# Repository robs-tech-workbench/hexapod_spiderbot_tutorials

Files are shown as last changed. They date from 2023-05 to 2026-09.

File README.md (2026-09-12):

# Spider Robot Tutorials

## Tutorials on Catch IT

Read the companion articles on [Catch IT — Robert Meisner's website](https://catchit.pl/). These link back to the source code and include build context, tests and limitations.

- [Building My 3D-Printed Hexapod](https://catchit.pl/blog/building-3d-printed-hexapod-spider-robot/)
- [How the Hexapod Control Layers Fit Together](https://catchit.pl/blog/hexapod-servo-calibration-forward-inverse-kinematics/)
- [Building a Hexapod: Tools, Hardware and 3D-Printed Parts](https://catchit.pl/blog/hexapod-build-guide-tools-hardware-and-3d-printed-parts/)
- [Calibrating Hexapod Servos with a Servo Tester](https://catchit.pl/blog/calibrating-hexapod-servos-with-a-servo-tester/)
- [Controlling a Hexapod with a HID Gamepad](https://catchit.pl/blog/controlling-a-hexapod-with-a-hid-gamepad/)
- [Inverse Kinematics for a Hexapod Leg](https://catchit.pl/blog/inverse-kinematics-for-a-hexapod-leg/)
- [Forward Kinematics for a Hexapod Leg](https://catchit.pl/blog/forward-kinematics-for-a-hexapod-leg/)
- [Controlling One Hexapod Leg](https://catchit.pl/blog/controlling-one-hexapod-leg/)

Welcome to the Spider Robot Tutorials repository! This collection of tutorials is designed to help you build, program, and control a hexapod robot. We'll cover everything from the basics of robot mechanics and design to more advanced topics like inverse kinematics and control algorithms. Whether you're a beginner or a seasoned roboticist, there's something here for everyone.
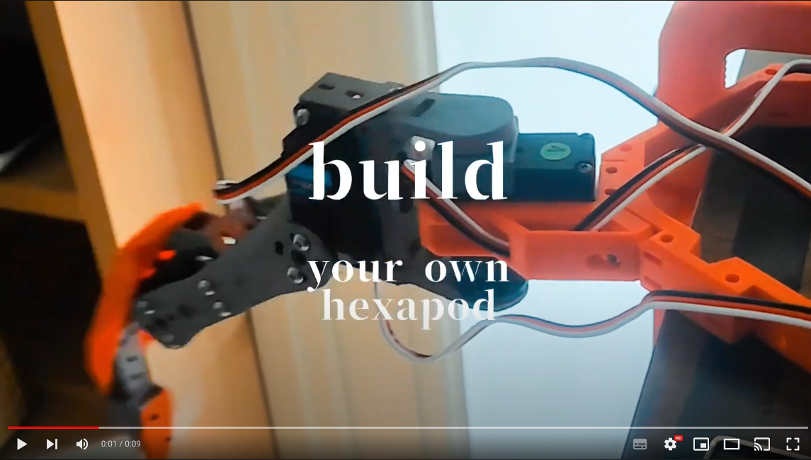
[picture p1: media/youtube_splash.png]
Watch the video (https://youtu.be/toPMHUULjyc)

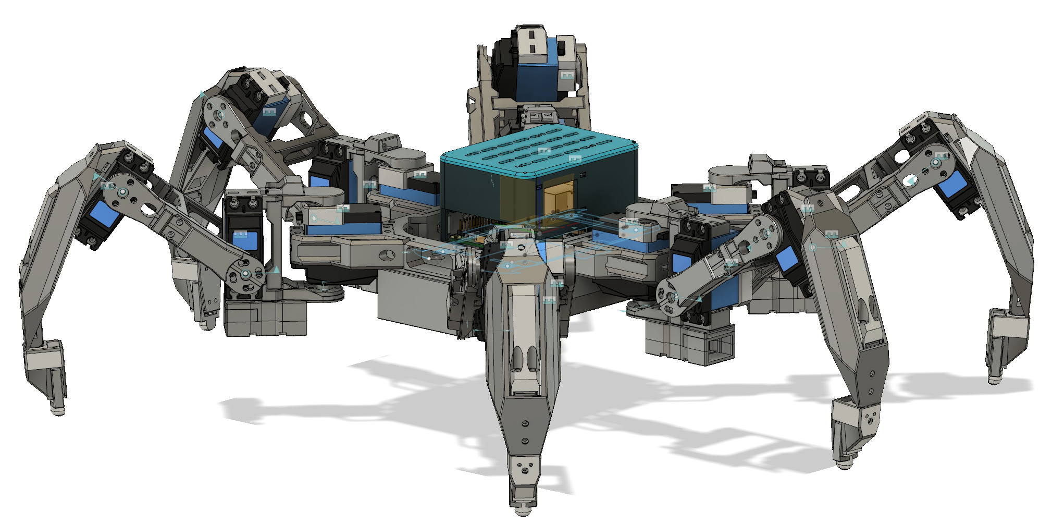
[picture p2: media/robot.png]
Hexapod robot spider

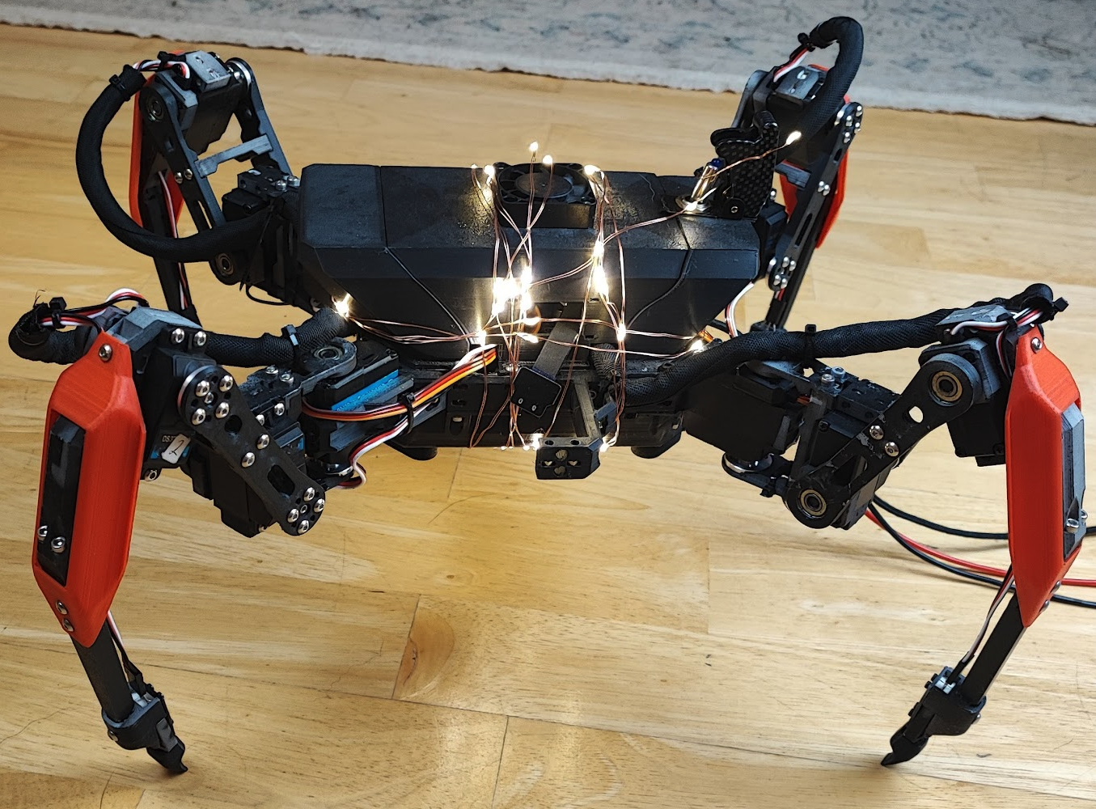
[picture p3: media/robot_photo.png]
SpiderBot photo

## Table of Contents
- Introduction to Hexapod Robotics
- [Tools, Hardware Components, and 3D Printed Parts](tutorial_tools_hardware_3d_parts_spider_robot/README.md)
- [Servo Calibration](tutorial_servo_calibration/README.md)
- [Controlling Your Robot Using USB or Bluetooth HID Devices](tutorial_controlling_robot_using_hid/README.md)
- [Programming the Hexapod: Basics](tutorial_controll_one_leg/README.md)
- [Inverse Kinematics for Spider Robot Legs](tutorial_inverse_kinematics/README.md)
- [Forward Kinematics for Spider Robot Legs](tutorial_forward_kinematics/README.md)
- Gait patterns - TBD
- Control Algorithms and Optimization - TBD
- Adding Sensors and Interactivity - TBD
- Artificial Intelligence - TBD

## Getting Started
To get started with the Spider Robot Tutorials, simply clone this repository or download the tutorials as a ZIP file. Each tutorial folder contains a README.md file, which serves as the main tutorial document. Follow the instructions provided in the README.md files, and you'll be on your way to building and programming your own hexapod robot!

## Contributing
We welcome contributions to the Hexapod Robotics Tutorials repository! If you have a new tutorial idea, an improvement to an existing tutorial, or any other suggestions, please feel free to open an issue or submit a pull request. Notable changes to this repository are tracked in [CHANGELOG.md](CHANGELOG.md).

## License
The content in this repository is licensed. For more information about the license terms and conditions, please refer to the [LICENSE](LICENSE) file in this repository.

Happy building!

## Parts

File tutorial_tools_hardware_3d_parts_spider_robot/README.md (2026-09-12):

Read the companion tutorial on [Catch IT](https://catchit.pl/): [Building a Hexapod: Tools, Hardware and 3D-Printed Parts](https://catchit.pl/blog/hexapod-build-guide-tools-hardware-and-3d-printed-parts/).

# Spider Robot Building Guide: Tools, Hardware Components, and 3D Printed Parts

> **Disclaimer:** This guide is a part of an extensive series focused on constructing a spider robot from scratch. Each installment targets a specific topic to provide you with a comprehensive understanding of the entire process. Whether you are a beginner or an expert in robotics, these resources aim to be both insightful and instructive. Happy building! To access the full series, click [here](../README.md).

## Introduction and Inspiration

The inception of this project can be traced back to a YouTube video from the 'Make Your Own Pet' series. This particular venture piqued my interest as an engaging and educational pastime during the long days of COVID-19 quarantines. To put it in short, the idea is to use a smartphone as the main controller for your hobby project. If you have questions or would like to become part of a community interested in similar projects, I recommend joining their [discord](https://www.makeyourpet.com/) or exploring their [GitHub](https://github.com/makeyourpet/hexapod) and [YouTube](https://www.youtube.com/makeyourpet) channels.
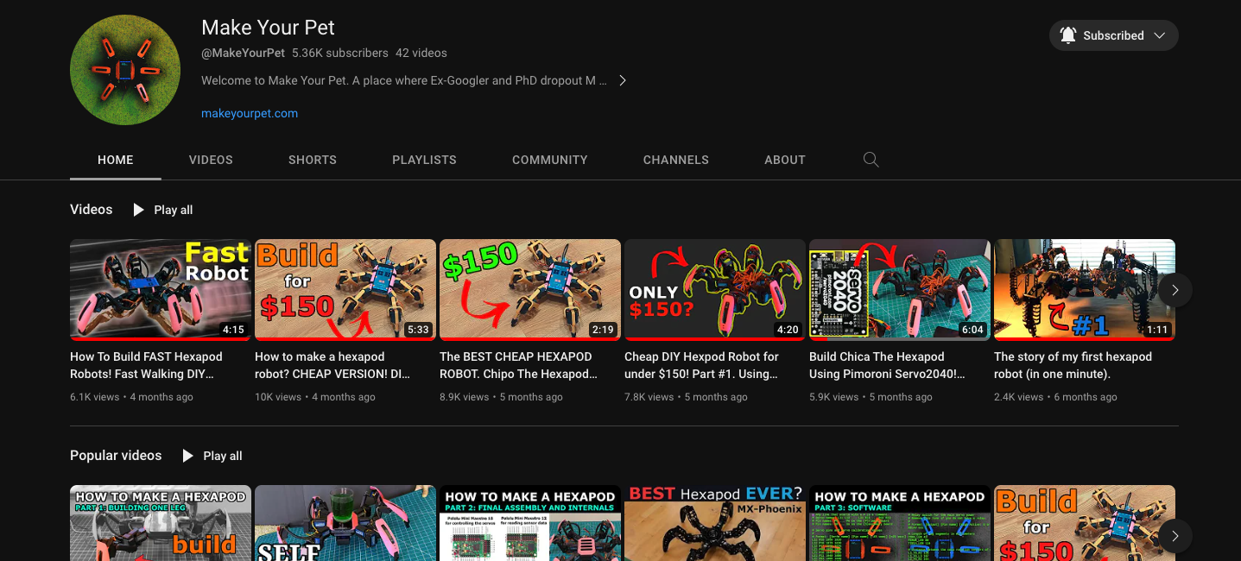
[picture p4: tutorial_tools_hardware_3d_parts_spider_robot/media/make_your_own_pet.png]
Make Your Own Pet

## Affiliation

**I am not affiliated** with any of the companies that manufacture the components used in this project. The links provided are not affiliate links and are included solely for informational purposes. The information is based on my personal experience and is intended for educational use. I strongly recommend conducting your own research and consulting various sources before making any purchasing decisions or implementing these components into your projects.

---
## 3D Printing and Design

**The repository with the most up-to-date 3D parts and other designs can be found here: [https://github.com/robert-s-workshop/hexapod_spiderbot_model](https://github.com/robert-s-workshop/hexapod_spiderbot_model)**

I leveraged Fusion 360 to design custom components for my spider robot, even without extensive CAD experience. I opted for black PLA filament, which offers a good blend of strength, safety, and affordability.

I decided **not to use** the official MakeYourPet 3D parts. Instead, I discovered that one of the Discord server users, named 'amelendez8', was working on his own design [here](https://github.com/almelnz2005/hexapod).
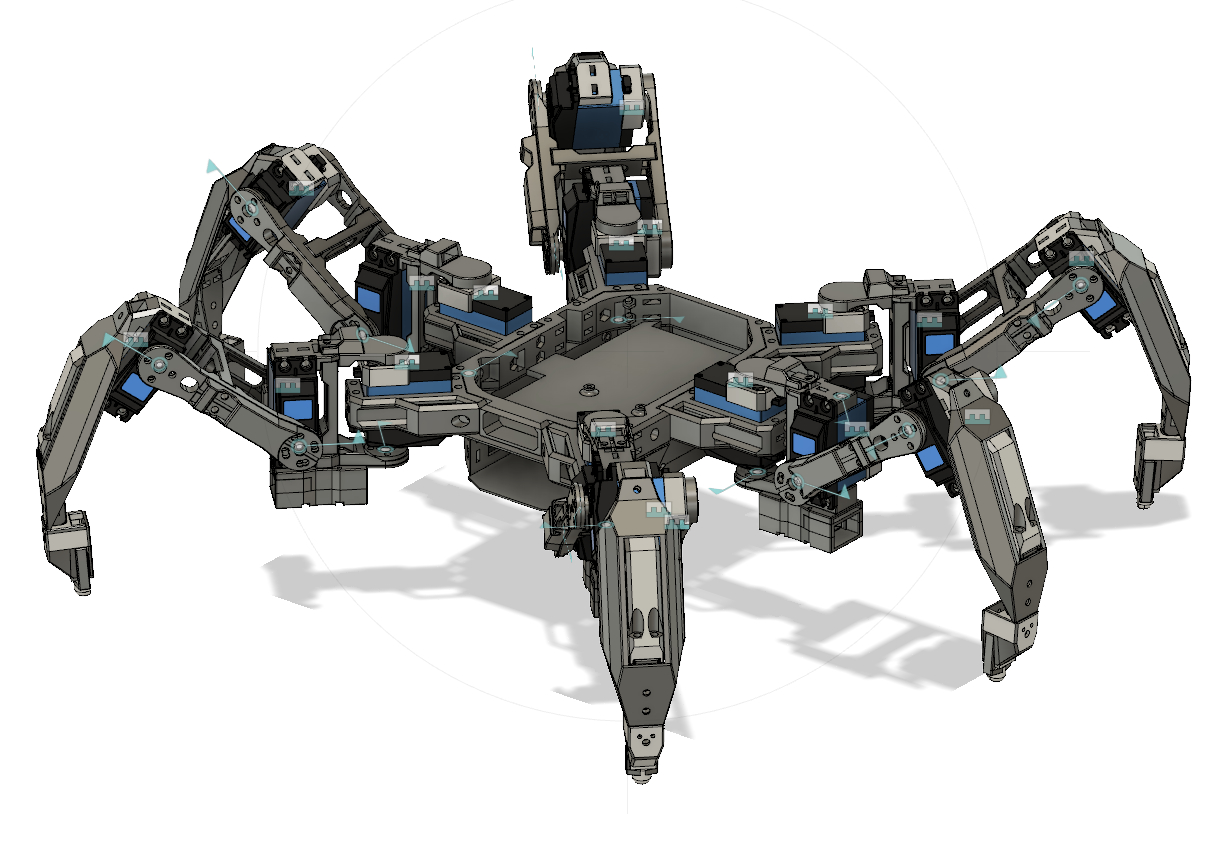
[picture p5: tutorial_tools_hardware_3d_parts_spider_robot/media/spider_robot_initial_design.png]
Original Robot Design


 Since this design was very modular, he shared the source files, the license was permissive, and I liked the techy look and feel, I decided to adjust the design to meet my needs.

The design process was iterative and took considerable time. Initially, I designed a separate enclosure for the Raspberry Pi and servo controller. 
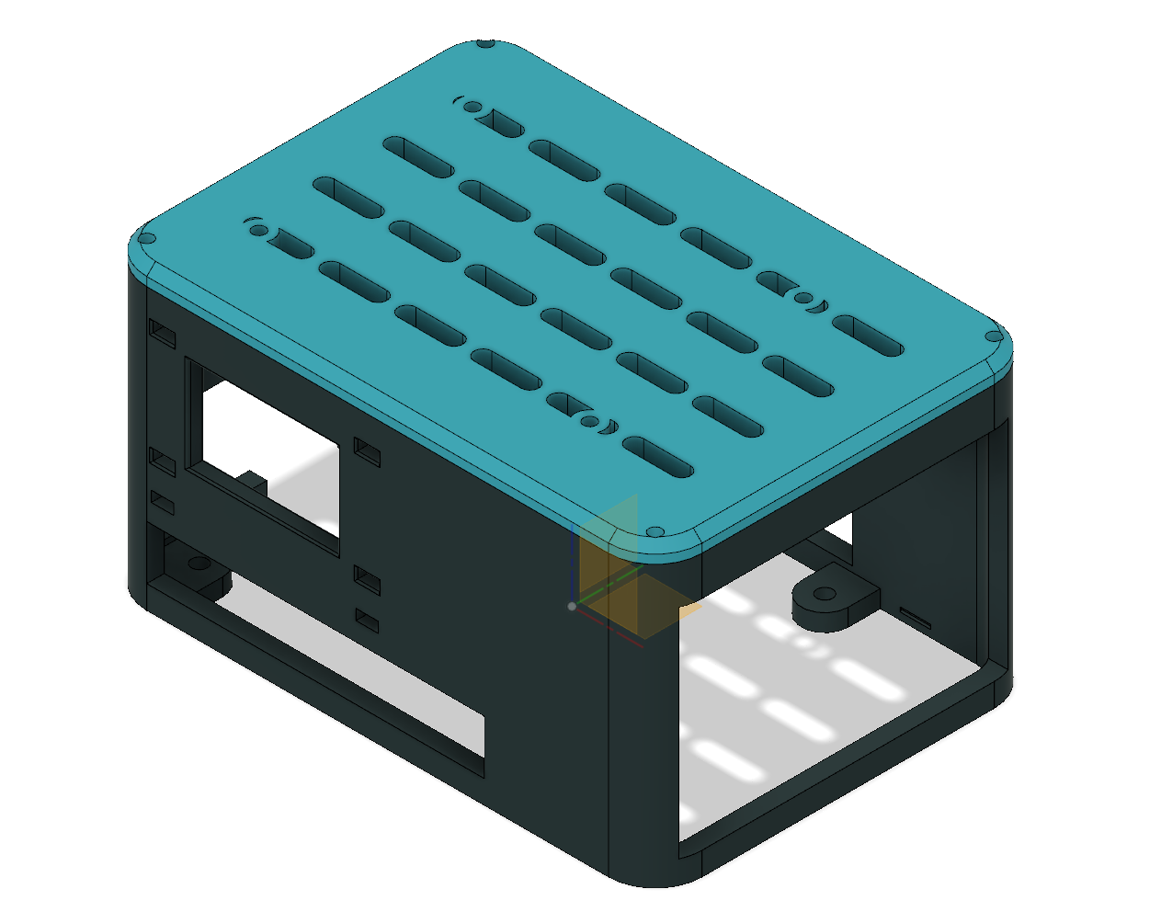
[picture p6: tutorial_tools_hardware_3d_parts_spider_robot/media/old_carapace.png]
New electronics enclosure, robot spider carapace

However, this initial design was visually and functionally disjointed from the overall aesthetic and architecture of the robot.
Realizing the limitations, I opted for a more integrated approach by designing a larger spider robot carapace. 

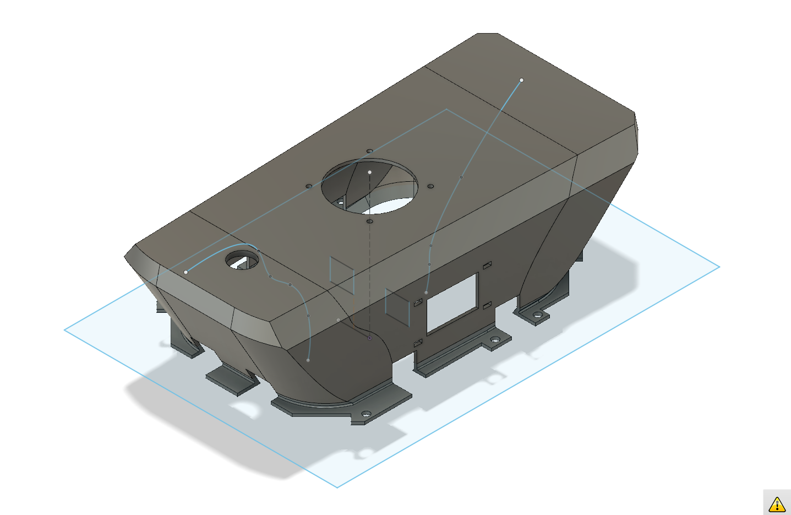
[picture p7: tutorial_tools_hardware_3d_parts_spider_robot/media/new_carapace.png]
New electronics enclosure, robot spider carapace


This new design was superior for several reasons. Firstly, it provided a unified, streamlined look that harmonized with the other modular components. Secondly, the carapace could accommodate and neatly conceal all the electronics, eliminating the clutter of exposed wires and creating a cleaner, more professional appearance. 
Lastly, this unified housing simplified the assembly process, making it easier to access components for future upgrades or maintenance.
First electronics enclosure
I initially made the mistake of placing the Raspberry Pi at the bottom, with the servo controller suspended above it. This configuration made it challenging to open the carapace without detaching all the servo cables. To rectify this, I later repositioned the Raspberry Pi on the roof of the body while keeping the servo controller attached to the floor.

The carapace also underwent several minor modifications to optimize the available internal space.

Next, I decided to replace the bolt-like joint design with one that utilizes bearings. This required reworking every joint in the legs, which basically consisted of two parts.

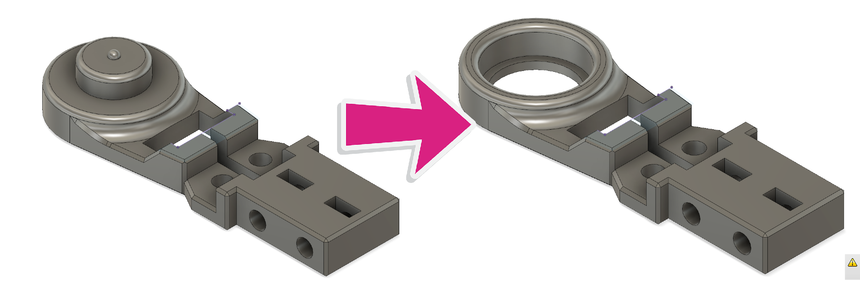
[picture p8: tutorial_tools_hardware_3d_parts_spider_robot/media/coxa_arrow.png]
Bearings, leg joints, coxa

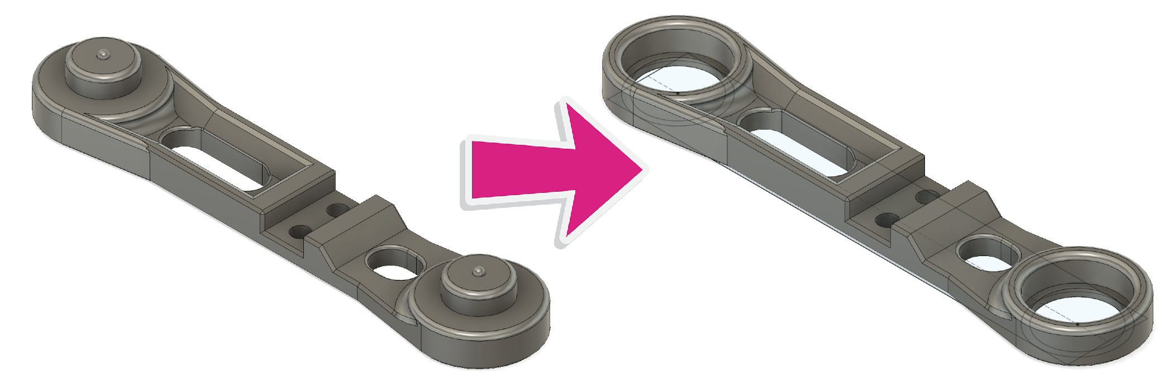
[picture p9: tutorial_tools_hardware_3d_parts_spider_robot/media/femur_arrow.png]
Bearings, leg joints, femur

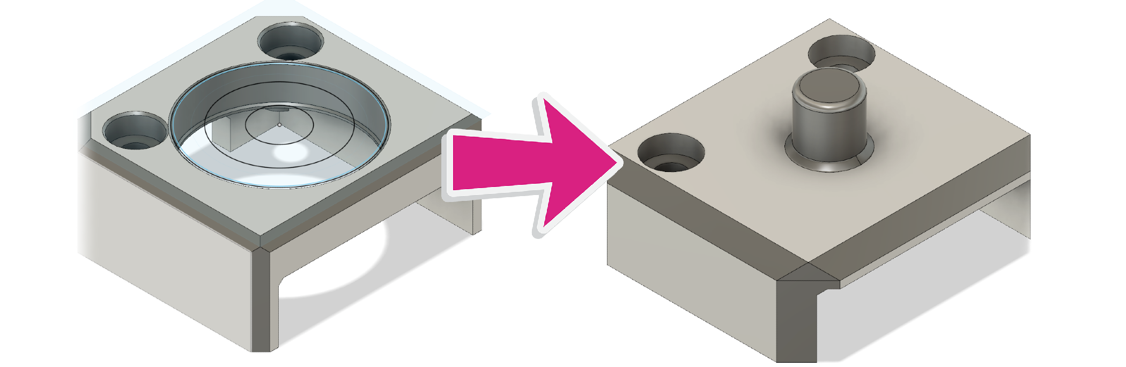
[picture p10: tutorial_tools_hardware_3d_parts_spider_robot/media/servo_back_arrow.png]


Since I started with a quadruped robot, balancing it during walking was a significant challenge. After some tests, I discovered that the robot could benefit from a larger range of movement. To achieve this, I needed to extend the length of the leg's tibia.
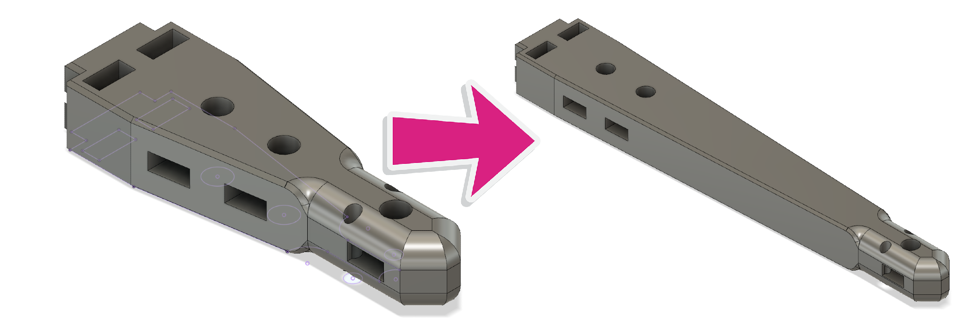
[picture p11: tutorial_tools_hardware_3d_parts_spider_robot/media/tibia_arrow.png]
Spider robot, longer tibia


Finally, I made some holes in the body to accommodate the on/off switch, some LCD screens, and the cooling fan.

Spider robot

**The repository with the most up-to-date design can be found here: [https://github.com/robert-s-workshop/hexapod_spiderbot_model](https://github.com/robert-s-workshop/hexapod_spiderbot_model)**

## Hardware Components

### Servo Motors: Coreless vs. Brushless, Range and Resolution Considerations

When building a spider robot, the type of servo motor you choose is paramount. Coreless high-speed, high-torque servo motors with a rating of 35kg+ are recommended for this project. However, brushless motors with positional feedback provide greater accuracy and longevity, though they come with a hefty price tag. 

Servos

When selecting a servo motor for your project, it's crucial to consider the range of motion you'll need. Servo motors commonly come in ranges like 180° or 270°. A servo with a wider range (e.g., 270°) will offer more flexibility in movement but may have a lower resolution, meaning less precise control over small movements. On the other hand, a 180° servo might offer higher resolution, allowing for more precise positioning but with a limited range. Choose a servo that best fits the specific requirements of your project for optimal performance.
[Servo Motors i have used on Aliexpress](https://pl.aliexpress.com/item/33010787343.html)

### Servo Mounting: Metal 25T Servo Arm Round Type

For robust and reliable servo mounting, I recommend using Metal Servos Mount Aluminum Metal 25T Servo Arm Round Type. These mounts are made of high-quality aluminum, providing excellent durability and stability. The 25T round type design ensures a secure fit and optimal torque transfer, making it an ideal choice for projects that require precise and consistent servo movements.
[Metal Servos Mount Aluminum Metal 25T Servo Arm Round Type on Aliexpress](https://www.aliexpress.com/item/32966238529.html)
Metal 25T Round Servo Arm

### Micro Switches for Leg Sensors

Touch-sensitive micro switches act as leg sensors, providing crucial input for the robot's movement algorithms. 
These can be easily procured from [Amazon](https://www.amazon.co.uk/gp/product/B07YDFH7H3).
Micro Switches for Leg Sensors

### Servo Controller 

The Servo 2040 - 18 Channel Servo Controller is the backbone for servo operations. Its firmware aligns with the 'Make Your Own Pet' project, and I've crafted a Python class for easy communication with the spider's 'brain.'
[Servo 2040 - 18 Channel Servo Controller](https://shop.pimoroni.com/products/servo-2040?variant=39800591679571)
The Servo 2040

#### Why This Controller is a Good Choice
- **Versatile**: Supports up to 18 servos, ideal for complex robotics.
- **Power Monitoring**: Built-in current tracking for optimized power use.
- **Visual Feedback**: Six RGB LEDs for immediate status updates.
- **Sensor Support**: Headers for six analog sensors for added functionalities.
- **RP2040 Core**: Benefits from the flexibility of RP2040's Programmable IOs (PIOs).

### The Spider Brain: Raspberry Pi 4 Model B

A Raspberry Pi 4 Model B or a similar board that supports a Linux-based OS and Python environment is ideal for executing the robot's complex logic. This includes gait algorithms, sensor inputs, and communication with the Gamepad controller.

Raspberry

### Servo Extension Cables 

Investing in both long (30cm) and short (10-15cm) extension cables saves you from having to engage in tedious cable management. 

[Servo Extension Cables on Amazon](https://www.amazon.co.uk/gp/product/B06W9MRNWL).

Servo Extension Cable

### Cable Management: Braided Cable Sleeve PET Self Closing

Effective cable management is crucial for both aesthetics and functionality. I recommend using a Braided Cable Sleeve PET Self Closing for wrapping loose cables. This sleeve is not only easy to use but also provides a clean and organized look to your project. Its self-closing feature ensures that your cables stay securely bundled, reducing the risk of tangling or snagging. 

[Braided Cable Sleeve PET Self Closing on Aliexpress](https://www.aliexpress.com/item/4000279970497.html)

Braided Cable Sleeve

### Bearings

For smooth mechanical performance, bearings are an essential part of the 3D printed components. If you opt for a different 3D model, ensure your bearings are compatible. For my design use model 625zz. There are 3D printed robot designs available that do not need those - just check 'Make Your Own Pet' project.
Bearings

### Power Control: 12V Illuminated LED Toggle Switch Aircraft Missile Flip

To easily control the power supply to the robot, I've used a 12V Illuminated LED Toggle Switch Aircraft Missile Flip. This toggle switch not only serves the functional purpose of turning the robot on and off but also adds a bit of aesthetic appeal with its illuminated LED and aircraft missile flip design.
12V Illuminated LED Toggle Switch Aircraft Missile Flip

### Power Source: 2S Lipo Battery

The Zeee 2S Lipo Battery 6200mAh 7.4V 60C is an excellent fit for this project, easily fitting into the robot's battery compartment. I decided to solder an XT30 plug for compatibility with the rest of my build. 

[The Zeee 2S Lipo Battery 6200mAh 7.4V 60C on amazon UK](https://www.amazon.co.uk/gp/product/B07YD6282M)
Zeee 2S Lipo Battery

### Wires: Selecting the Right Gauge and Insulation

Choosing the correct wires is essential for both the functionality and safety of your project. For signal wires, I highly recommend using 22-24 AWG, as these gauges are generally suitable for low-current signal transmission. For power wires, 14-16 AWG is the go-to choice to ensure they can handle the current without overheating. I strongly advise opting for silicon-covered wires; they offer superior heat resistance and flexibility compared to other types of insulation. Silicon-covered wires are also more manageable when working in tight spaces or routing through complex assemblies.
Silicon Wires

### 5V Step Down Buck Module

To convert the 7.4V from your battery to a stable 5V for the Raspberry Pi, a step-down buck module is essential. Opt for one that can deliver at least 3A of current. 
[2A 5V Step Down Buck Module I have used on Aliexpress (you might need 3A)](https://www.aliexpress.com/item/4000084079149.html)
5V Step Down Buck Module

---

## ⚠️ CRITICAL: Power Safety Warning

**When operating with both battery and USB connected, you MUST take precautions to prevent power backfeed damage.**

### The Risk
Connecting battery power and USB power simultaneously without proper precautions can cause **permanent hardware damage** to your:
- Raspberry Pi (power management IC failure)
- Servo 2040 (power transistor failure, can cause voltage feedback or overcurrent conditions)
- Computer/laptop (via USB backfeed)

### Required Safety Measures

You **MUST** use one of these solutions when connecting battery and USB at the same time:

1. **Use a data-only USB cable** (recommended for development)
   - This is a USB cable with the VBUS (+5V power) pin disconnected while keeping data and ground pins connected
   - Allows programming and communication without power backfeed risk
   - Essential when programming a battery-powered robot through USB

2. **Cut the "Separate USB and Ext. Power" trace** on the Servo 2040 back
   - This physically separates USB power from external battery power on the board
   - See the [Servo 2040 product page](https://shop.pimoroni.com/products/servo-2040) for details
   - Permanent modification - recommended only if you always use external power

### Important Notes
- The Servo 2040 official documentation includes this critical warning that must not be ignored
- **Never connect both battery and standard USB simultaneously** without one of the above precautions
- When in doubt, disconnect the battery before connecting USB for programming
- For production use, choose your power source: battery OR USB, not both

⚠️ **Failure to follow these precautions can result in expensive equipment damage within minutes.**

For more information, refer to the official [Servo 2040 documentation](https://shop.pimoroni.com/products/servo-2040).

---

### USB Cables

Two types of USB cables are needed:
- A short USB-A to USB-C for connecting the Raspberry Pi to the Servo Controller. 
[A short USB-A to USB-C on Aliexpress](https://www.aliexpress.com/item/1005005240135902.html)
- A long USB-A to USB-C for development purposes, allowing seamless interfacing between your laptop and the robot. 
USB Cable

---

## Additional Supplies and Tools

### Gamepad Controller 

A Human Interface Device (HID)-compatible gamepad controller is necessary for direct control of the spider robot's movement. The Radiomaster TX16S is a reliable choice, offering both USB and Bluetooth connectivity (with additional module). You can choose any HID compatible controller.
Radiomaster TX16S

### Screws: Choosing the Right Type and Size

For this project, it's crucial to select the right screws to ensure durability and ease of assembly. I highly recommend using hexagonal bit screws over traditional flat or cross-head screws. They offer superior torque control and are generally easier to work with.  
[You can find sets of these screws available on Amazon UK](https://www.amazon.co.uk/gp/product/B093ZKJHX6).

Hexagonal Bit Screws

**Note**: Be cautious when purchasing screw sets; make sure to buy sets with consistent hex socket sizes. I made the mistake of buying two different sets with varying hex socket sizes, which complicated the assembly process. Two M3 sets (around 500 pieces each) of mixed sizes should have you covered for this project.

### Fasteners/Zip Ties
You will need a lot of zip ties to keep all your cables under control. Zip ties are not only an inexpensive but also an effective solution for managing the maze of wires that power the servos, sensors, and the central processing unit. Opt for a variety pack that includes ties of multiple lengths and widths, as you'll find various applications for each size. High-quality zip ties are recommended for long-lasting durability, especially since the cables will often be in motion, causing wear and tear on the ties themselves.
Fasteners/Zip Ties
## Other Tools
- **Scalpel Knife/Box cutter:** After 3D printing, it's common to have some imperfections or excess material on your parts. A Scalpel Knife is an excellent tool for cleaning up these minor flaws. It allows for precise cuts and can easily remove brims, supports, or any other unwanted material, leaving you with a cleaner, more professional-looking component.
[Scalpel Knife on Aliexpress](https://www.aliexpress.com/item/1005004898484210.html)

- **Soldering Set:** A USB-powered soldering iron is portable and can be used in field adjustments. 
Additionally, a soldering third arm can be incredibly helpful for holding components in place while you work, and a soldering cleaner is essential for maintaining the tip of your soldering iron, thereby ensuring more precise and effective soldering.
Soldering Set
USB-powered soldering iron
- **Mini Cordless Precision Electric Screwdriver:** Given the hundreds of screws you'll be working with, this tool is indispensable.
Mini Cordless Precision Electric Screwdriver
- **Digital Servo/ESC Consistency Tester:** This is crucial for calibrating and testing your servo motors.
Digital Servo/ESC Consistency Tester
- **Multimeter:** It's highly advisable to use a multimeter during the setup and testing phases. A multimeter will allow you to accurately measure voltage, current, and resistance, ensuring that all components, including the Servo Controller or Raspberry, are operating within their specified ranges. This is crucial for both the safety and the successful execution of your project.
Multimeter
---

---

By following this guide, you'll have a comprehensive understanding of the hardware, electronics, and additional supplies needed to build your own spider robot. Feel free to dive into each section for a more in-depth understanding, and happy building!

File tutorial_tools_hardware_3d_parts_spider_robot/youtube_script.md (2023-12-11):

# Spider Robot Building Guide: Tools, Hardware Components, and 3D 

The inception of this project can be traced back to a YouTube video from the 'Make Your Own Pet' series. This particular venture piqued my interest as an engaging and educational pastime during the long days of COVID-19 quarantines. To put it in short, the idea is to use a smartphone as the main controller for your hobby project. If you have questions or would like to become part of a community interested in similar projects, I recommend joining their discord or exploring their GitHub and YouTube channels.

## Disclaimer
**I am not affiliated** with any of the companies that manufacture the components used in this project. The links provided are not affiliate links and are included solely for informational purposes. The information is based on my personal experience and is intended for educational use. I strongly recommend conducting your own research and consulting various sources before making any purchasing decisions or implementing these components into your projects.

---
## 3D Printing and Design

**The repository with the most up-to-date 3D parts and other designs can be found in the description**

I leveraged Fusion 360 to design custom components for my spider robot, even without extensive CAD experience. I opted for black PLA filament, which offers a good blend of strength, safety, and affordability.

I decided **not to use** the official MakeYourPet 3D parts. Instead, I discovered that one of the Discord server users, named 'amelendez8', was working on his own design.

 Since this design -was very modular, -he shared the source files, the license was permissive, -and I liked the techy look and feel, 
 I decided to adjust the design to meet my needs.

The design process was iterative and took considerable time. Initially, I designed a separate enclosure for the Raspberry Pi and servo controller. 
However, this initial design was visually and functionally disjointed from the overall aesthetic and architecture of the robot.
Realizing the limitations, I opted for a more integrated approach by designing a larger spider robot carapace. 

This new design was superior for several reasons. Firstly, it provided a unified, streamlined look that harmonized with the other modular components. Secondly, the carapace could accommodate and neatly conceal all the electronics, eliminating the clutter of exposed wires and creating a cleaner, more professional appearance. 
Lastly, this unified housing simplified the assembly process, making it easier to access components for future upgrades or maintenance.

I initially made the mistake of placing the Raspberry Pi at the bottom, with the servo controller suspended above it. This configuration made it challenging to open the carapace without detaching all the servo cables. To rectify this, I later repositioned the Raspberry Pi on the roof of the body while keeping the servo controller attached to the floor.

The carapace also underwent several minor modifications to optimize the available internal space.

Next, I decided to replace the bolt-like joint design with one that utilizes bearings. This required reworking every joint in the legs, which basically consisted of two parts.

Since I started with a quadruped robot, balancing it during walking was a significant challenge. After some tests, I discovered that the robot could benefit from a larger range of movement. To achieve this, I needed to extend the length of the leg's tibia.

Finally, I made some holes in the body to accommodate the on/off switch, some LCD screens, and the cooling fan.

**The repository with the most up-to-date design can be found in the description**

When building a spider robot, the type of servo motor you choose is paramount. Coreless high-speed, high-torque servo motors with a rating of 35kg+ are recommended for this project. However, brushless motors with positional feedback provide greater accuracy and longevity, though they come with a hefty price tag. 

When selecting a servo motor for your project, it's crucial to consider the range of motion you'll need. Servo motors commonly come in ranges like 180° or 270°. A servo with a wider range will offer more flexibility in movement but may have a lower resolution, meaning less precise control over small movements. On the other hand, a 180° servo might offer higher resolution, allowing for more precise positioning but with a limited range. Choose a servo that best fits the specific requirements of your project for optimal performance.

### Servo Mounting: Metal 25T Servo Arm Round Type

For robust and reliable servo mounting, I recommend using Metal and Round servo arm. These mounts are made of high-quality aluminum, providing excellent durability and stability. The 25T round design ensures a secure fit and optimal torque transfer, making it an ideal choice for projects that require precise and consistent servo movements.

### Micro Switches for Leg Sensors

Touch-sensitive micro switches act as leg sensors, providing crucial input for the robot's movement algorithms. 

### Servo Controller 

The Servo 2040 - 18 Channel Servo Controller is the backbone for servo operations. Its firmware aligns with the 'Make Your Own Pet' project, and I've crafted a Python class for easy communication with the spider's 'brain.'

Why This Controller is a Good Choice?
Well, It supports up to 18 servos, ideal for complex robotics.
It has a Built-in current tracking for optimized power use.
It provides Visual Feedback with Six RGB LEDs for immediate status updates.
It supports up to six analog sensors for added functionalities.
It Benefits from the flexibility of RP2040's Programmable IOs .

### The Spider Brain: Raspberry Pi 4 Model B

A Raspberry Pi 4 Model B or a similar board that supports a Linux-based OS and Python environment is ideal for executing the robot's complex logic. This includes gait algorithms, sensor inputs, and communication with the Gamepad controller.

### Servo Extension Cables 

Investing in both long (30cm) and short (10-15cm) extension cables saves you from having to engage in tedious cable management. 

### Cable Management: Braided Cable Sleeve PET Self Closing

Effective cable management is crucial for both aesthetics and functionality. I recommend using a Braided Cable Sleeve PET Self Closing for wrapping loose cables. This sleeve is not only easy to use but also provides a clean and organized look to your project. Its self-closing feature ensures that your cables stay securely bundled, reducing the risk of tangling or snagging. 

### Bearings

For smooth mechanical performance, bearings are an essential part of the 3D printed components. If you opt for a different 3D model, ensure your bearings are compatible. For my design use model 625zz. There are 3D printed robot designs available that does not need those - just check 'Make Your Own Pet' project.

### Power Control: 12V Illuminated LED Toggle Switch Aircraft Missile Flip

To easily control the power supply to the robot, I've used a 12V Illuminated LED Toggle Switch Aircraft Missile Flip. This toggle switch not only serves the functional purpose of turning the robot on and off but also adds a bit of aesthetic appeal with its illuminated LED and aircraft missile flip design.

### Power Source: 2S Lipo Battery

The Zeee 2S Lipo Battery 6200mAh 7.4V 60C is an excellent fit for this project, easily fitting into the robot's battery compartment. I decided to solder an XT30 plug for compatibility with the rest of my build. 

### Wires: Selecting the Right Gauge and Insulation

Choosing the correct wires is essential for both the functionality and safety of your project. For signal wires, I highly recommend using 22-24 AWG, as these gauges are generally suitable for low-current signal transmission. For power wires, 14-16 AWG is the go-to choice to ensure they can handle the current without overheating. I strongly advise opting for silicon-covered wires; they offer superior heat resistance and flexibility compared to other types of insulation. Silicon-covered wires are also more manageable when working in tight spaces or routing through complex assemblies.

### 5V Step Down Buck Module

To convert the 7.4V from your battery to a stable 5V for the Raspberry Pi, a step-down buck module is essential. Opt for one that can deliver at least 3A of current. 

### USB Cables

Two types of USB cables are needed:
- A short USB-A to USB-C for connecting the Raspberry Pi to the Servo Controller. 

- A long USB-A to USB-C for development purposes, allowing seamless interfacing between your laptop and the robot. 

---

## Additional Supplies and Tools

### Gamepad Controller 

A Human Interface Device (HID)-compatible gamepad controller is necessary for direct control of the spider robot's movement. The Radiomaster XT16S is a reliable choice, offering both USB and Bluetooth connectivity (with additional module). You can choose any HID compatible controller.

### Screws: Choosing the Right Type and Size

For this project, it's crucial to select the right screws to ensure durability and ease of assembly. I highly recommend using hexagonal bit screws over traditional flat or cross-head screws. They offer superior torque control and are generally easier to work with.  

**Note**: Be cautious when purchasing screw sets; make sure to buy sets with consistent hex socket sizes. I made the mistake of buying two different sets with varying hex socket sizes, which complicated the assembly process. Two M3 sets (around 500 pieces each) of mixed sizes should have you covered for this project.

### Fasteners/Zip Ties
You will need a lot of zip ties to keep all your cables under control. Zip ties are not only an inexpensive but also an effective solution for managing the maze of wires that power the servos, sensors, and the central processing unit. Opt for a variety pack that includes ties of multiple lengths and widths, as you'll find various applications for each size. High-quality zip ties are recommended for long-lasting durability, especially since the cables will often be in motion, causing wear and tear on the ties themselves.

## Other Tools
- **Scalpel Knife/Box cutter:** After 3D printing, it's common to have some imperfections or excess material on your parts. A Scalpel Knife is an excellent tool for cleaning up these minor flaws. It allows for precise cuts and can easily remove brims, supports, or any other unwanted material, leaving you with a cleaner, more professional-looking component.

- **Soldering Set:** A USB-powered soldering iron is portable and can be used in field adjustments. 
Additionally, a soldering third arm can be incredibly helpful for holding components in place while you work, and a soldering cleaner is essential for maintaining the tip of your soldering iron, thereby ensuring more precise and effective soldering.

- **Mini Cordless Precision Electric Screwdriver:** Given the hundreds of screws you'll be working with, this tool is indispensable.

- **Digital Servo/ESC Consistency Tester:** This is crucial for calibrating and testing your servo motors.

- **Multimeter:** It's highly advisable to use a multimeter during the setup and testing phases. A multimeter will allow you to accurately measure voltage, current, and resistance, ensuring that all components, including the Servo Controller or Raspberry, are operating within their specified ranges. This is crucial for both the safety and the successful execution of your project.

---

---

By following this guide, you'll have a comprehensive understanding of the hardware, electronics, and additional supplies needed to build your own spider robot. Feel free to dive into each section for a more in-depth understanding, and happy building!

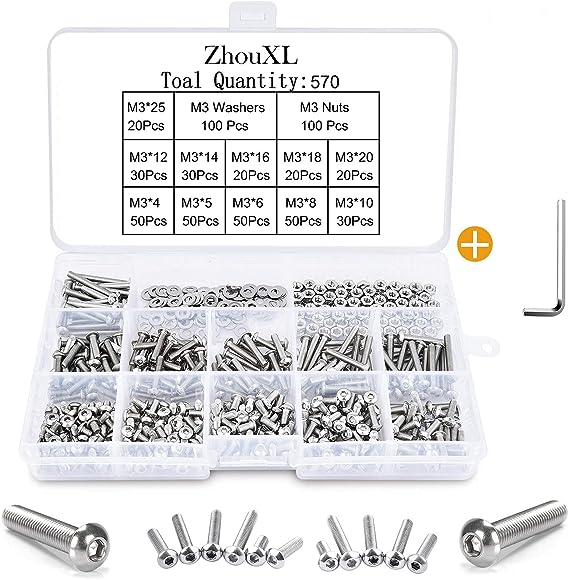
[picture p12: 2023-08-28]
tutorial_tools_hardware_3d_parts_spider_robot/media/81YxCIYD7zL._AC_SX569_.jpg

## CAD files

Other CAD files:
tutorial_inverse_kinematics/Hexapod_Leg_Fusion360.f3d

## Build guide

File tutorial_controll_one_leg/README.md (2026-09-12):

Read the companion tutorial on [Catch IT](https://catchit.pl/): [Controlling One Hexapod Leg](https://catchit.pl/blog/controlling-one-hexapod-leg/).

> **Disclaimer:** This tutorial is part of a comprehensive series that I've created to guide you through the process of building a spider robot. Each tutorial in the series is designed to cover a specific aspect of the project, providing detailed instructions and insights to help you understand and replicate the steps.
> 
> You can find the entire series [here](../README.md). I encourage you to explore all the tutorials in the series to gain a complete understanding of the project. Whether you're a beginner or an expert, I hope you find these resources helpful and informative. Happy building!

# Controlling One Hexapod Leg

This tutorial covers the basics of programming the hexapod: the `SpiderLeg` class with forward and inverse kinematics, simulation and visualization of a single leg, and mapping joint angles to servo pulse widths on the real hardware.

## Resources

- [`spider_leg.py`](spider_leg.py) — the `SpiderLeg` class implementing forward and inverse kinematics for a three-joint leg (coxa, femur, tibia).
- [`one_leg_controll.ipynb`](one_leg_controll.ipynb) — Jupyter notebook that simulates the leg, moves the tip through a set of positions, and projects paths onto the plane defined by those positions.
- [`image_processing.ipynb`](image_processing.ipynb) — image processing helper notebook (OpenCV): it turns a drawing ([`rip.jpg`](rip.jpg)) into paths that can be projected onto the leg's working plane.
- [`hardware_controller.py`](hardware_controller.py) — the `Servo`, `HardwareController`, and `ChicaController` classes for converting joint angles to servo pulse widths and communicating with the servo controller over serial.

The servo configuration file used by `HardwareController` is described in the [Servo Calibration](../tutorial_servo_calibration/README.md) tutorial.

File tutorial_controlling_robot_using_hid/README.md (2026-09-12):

Read the companion tutorial on [Catch IT](https://catchit.pl/): [Controlling a Hexapod with a HID Gamepad](https://catchit.pl/blog/controlling-a-hexapod-with-a-hid-gamepad/).

> **Disclaimer:** This tutorial is part of a comprehensive series that I've created to guide you through the process of building a spider robot. Each tutorial in the series is designed to cover a specific aspect of the project, providing detailed instructions and insights to help you understand and replicate the steps.
> 
> You can find the entire series [here](../README.md). I encourage you to explore all the tutorials in the series to gain a complete understanding of the project. Whether you're a beginner or an expert, I hope you find these resources helpful and informative. Happy building!

## Tutorial: Controlling a Robot with a HID Game Controller

In this tutorial, we will learn how to use the `GamepadController` class I wrote to interact with a game controller as a Human Interface Device (HID) and finally control your robot. 
The tutorial covers the following steps:

1. Listing all HID devices
2. Connecting to a HID device
3. Understanding the raw output from the controller and the two-value transmission per channel
4. Identifying controller channels and configuring them
5. Writing a method to control a robot using the game controller

## Resources

This repository includes a [Jupyter Notebook](controlling_robot_using_hid.ipynb) that contains the code and visualizations. 

### Step 1: Listing all HID devices

Before we can use a HID device, we need to know its vendor ID, product ID, or name. The `list_hid_devices()` method in the `GamepadController` class can be used to list all connected HID devices along with their vendor IDs, product IDs, and names:

```python
GamepadController.list_hid_devices()

```

This static method will list all the HID devices connected to your computer, showing their vendor and product IDs as well as their product strings (names).

### Step 2: Connecting to a HID device
Once we know the vendor ID, product ID, or name of our game controller, we can use the connect() method to establish a connection:

```python
gamepad = hid.device()
controller = GamepadController(gamepad)
controller.connect(vendor_id=<vendor_id>, product_id=<product_id>)  # Replace with actual IDs
# OR
controller.connect(name=<device_name>)  # Replace with actual name
```

This will connect to the HID device with the given vendor ID and product ID, or name.

### Step 3: Understanding the raw output from the controller and the two-value transmission per channel
To better understand the raw output data from the HID device, you can use the print_raw_data() method:
```python
GamepadController.print_raw_data(gamepad)
```
This method will print the raw data received from the controller. Understanding this data is crucial for interpreting the controller's inputs.

Typically, a single channel of a HID device transmits information using two values: a base value and a multiplier. These two values are combined to create a larger data range. In the GamepadController class, this is handled in the process_input() method:

```python
def process_input(self, input_data):
    for channel, index in self.channels.items():
        first_byte = input_data[index]
        multiplier = input_data[index + 1]
        value = 255 * multiplier + first_byte
        self.channel_states[channel] = value
```
The first_byte is the base value, and multiplier is used to increase the range of the possible values. The final value for the channel is calculated by multiplying the multiplier by 255 and adding the base value.

To identify which channels correspond to which controller inputs, you can experiment by moving different parts of your controller and observing the changes in the raw data output. This will help you identify which indexes correspond to which controller inputs.

### Step 4: Identifying controller channels and configuring them
The GamepadController class allows you to define channels such as throttle, roll, yaw, and pitch. After identifying the channels by observing the changes in raw data output during different controller inputs, you can define the channels as follows:

```python
controller = GamepadController(gamepad, channels={'throttle': 0, 'roll': 1, 'yaw': 2, 'pitch': 3})
```

Then you can use the read_controller() method to read the current state of the game controller:

```python
controller_state = controller.read_controller()
print(controller_state)
```

The read_controller() method returns a dictionary containing the current state of all the defined channels.

### Step 5: Writing a method to control a robot using the game controller
With the ability to read the state of the game controller, you can now use this information to control a robot. The following is a simple pseudocode example of how to do this:

```python
while True:
    # Read the controller state (returns None when no new report is available)
    controller_state = controller.read_controller()

    if controller_state:
        # Get the state of the throttle and yaw channels
        throttle = controller_state.get('throttle')
        yaw = controller_state.get('yaw')

        # Use the throttle and yaw values to control the robot
        robot.move_forward(throttle)
        robot.turn(yaw)

    # Wait a short period of time before the next iteration
    time.sleep(0.1)
```
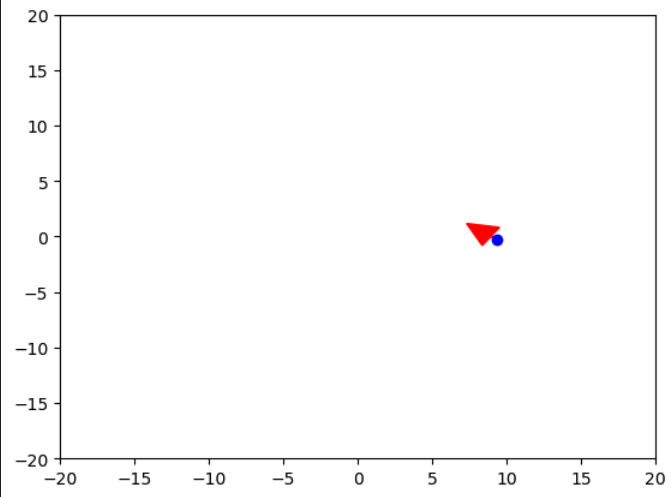
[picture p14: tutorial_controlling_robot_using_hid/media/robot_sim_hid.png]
Robot simulation using HID device


### Oh... Wait! What is HID?

HID stands for Human Interface Device. It's a type of computer device that interacts directly with, and most often takes input from, humans and may deliver output to humans. The term "HID" most commonly applies to the USB-HID specification. The USB-HID specification defines a device class (a type of computer hardware) that includes devices like keyboards, mice, game controllers, and even some more unusual devices like barcode readers.

HID devices are designed to be plug-and-play, which means that when you plug one of these devices into your computer, the operating system should automatically recognize it and load the appropriate drivers.

To identify a HID device, you can look for the following indicators:

1. Vendor ID and Product ID: Every USB device has a vendor ID and a product ID that uniquely identifies it. The vendor ID is a unique number assigned to the manufacturer by the USB standards group, and the product ID is chosen by the manufacturer and is unique to each product they make. You can see these IDs by inspecting the device's properties in your operating system's device manager, or by using software tools that list USB devices (like lsusb on Linux).
2. Device Class: The device class tells the operating system what type of device it is and how it should be handled. HID devices have a device class of 03.
3. Usage Page and Usage ID: The usage page and usage ID are part of the HID specification, and they tell the operating system what kind of input or output the device provides. For example, a mouse might have a usage page of 01 (Generic Desktop Controls) and a usage ID of 02 (Mouse).
4. In Python, you can use the hid library to interact with HID devices. You can list all HID devices connected to your computer using the hid.enumerate() function, which returns a list of dictionaries. Each dictionary contains information about one HID device, including its vendor ID, product ID, usage page, and usage ID.

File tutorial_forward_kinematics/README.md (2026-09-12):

Read the companion tutorial on [Catch IT](https://catchit.pl/): [Forward Kinematics for a Hexapod Leg](https://catchit.pl/blog/forward-kinematics-for-a-hexapod-leg/).

> **Disclaimer:** This tutorial is part of a comprehensive series that I've created to guide you through the process of building a spider robot. Each tutorial in the series is designed to cover a specific aspect of the project, providing detailed instructions and insights to help you understand and replicate the steps.
> 
> You can find the entire series [here](../README.md). I encourage you to explore all the tutorials in the series to gain a complete understanding of the project. Whether you're a beginner or an expert, I hope you find these resources helpful and informative. Happy building!

## Resources

This repository includes a [Jupyter Notebook](forward_kinematics.ipynb) that contains the code and visualizations. 

# Understanding the Forward Kinematics Method in a Spider Robot

Welcome, coding enthusiasts and aspiring roboticists! My goal is to document my journey of building a spider robot in the form of short but detailed tutorials. These tutorials will be easy for everyone to follow, packed with code examples and thorough explanations. Whether you're a seasoned coder or a beginner just starting out, I believe these guides will be a valuable resource in your learning journey. 

Today, in this installment of our exciting series on building a spider robot, we're going to delve into a vital aspect of robot motion planning - the forward kinematics method. Specifically, we'll be exploring the `forward_kinematics_naive` method in our `SpiderLeg` class.

# Forward Kinematics in Robotics

Forward kinematics is a term in robotics that refers to the calculation of the end effector's position (for instance, a robot arm's or a leg's tip position) given the joint angles. It's essentially about predicting the pose of a robot given its joint parameters.

For a spider-like robot, which could be a quadruped (4-legged) or hexapod (6-legged) robot, forward kinematics would involve determining the position of each of its feet given the angles of its joints. Each leg of the robot is typically a kinematic chain, with joints that allow movements in specific directions.

In practical terms, forward kinematics allows the robot to plan its movements. If the robot's brain decides to move a specific leg to a certain position, it can use inverse kinematics to calculate the necessary joint angles, then move the joints to those angles, and use forward kinematics to check that the leg ended up in the right place.

## Brief Introduction to Trigonometry

Before we dive into the code, let's briefly touch upon some basic trigonometry concepts that are used in this method:

- **Sine (sin)**: In a right-angled triangle, the sine of an angle is the length of the side opposite to that angle divided by the length of the hypotenuse (the longest side, opposite the right angle). This is expressed as: \(\sin(\theta) = \frac{{\text{{opposite}}}}{{\text{{hypotenuse}}}}\).

- **Cosine (cos)**: Similarly, the cosine of an angle in a right-angled triangle is the length of the side adjacent to the angle divided by the length of the hypotenuse. This is expressed as: \(\cos(\theta) = \frac{{\text{{adjacent}}}}{{\text{{hypotenuse}}}}\).

- **Tangent (tan)**: The tangent of an angle is defined as the ratio of the sine to the cosine of that angle, or equivalently, the ratio of the side opposite the angle to the side adjacent to the angle in a right-angled triangle. This is expressed as: \(\tan(\theta) = \frac{{\sin(\theta)}}{{\cos(\theta)}}\).

- **Pythagorean theorem**: In any right-angled triangle, the square of the length of the hypotenuse (the side opposite the right angle) is equal to the sum of the squares of the lengths of the other two sides. This can be written as \(a^2 + b^2 = c^2\), where \(c\) is the length of the hypotenuse, and \(a\) and \(b\) are the lengths of the other two sides.

These concepts allow us to calculate the lengths of sides in a right triangle when an angle is known, or to find an angle when the lengths of the sides are known. They form the basis for many geometric calculations and transformations, including those used in our forward kinematics.

Let's get started!

# The `forward_kinematics_naive` Method: A Deep Dive

In this tutorial, we'll dissect the `forward_kinematics_naive` method from the `SpiderLeg` class in our spider robot project. This method is pivotal for calculating the positions of the leg's joints based on the joint angles. Here's a detailed breakdown of each step, complete with trigonometry explanations and inline code snippets.
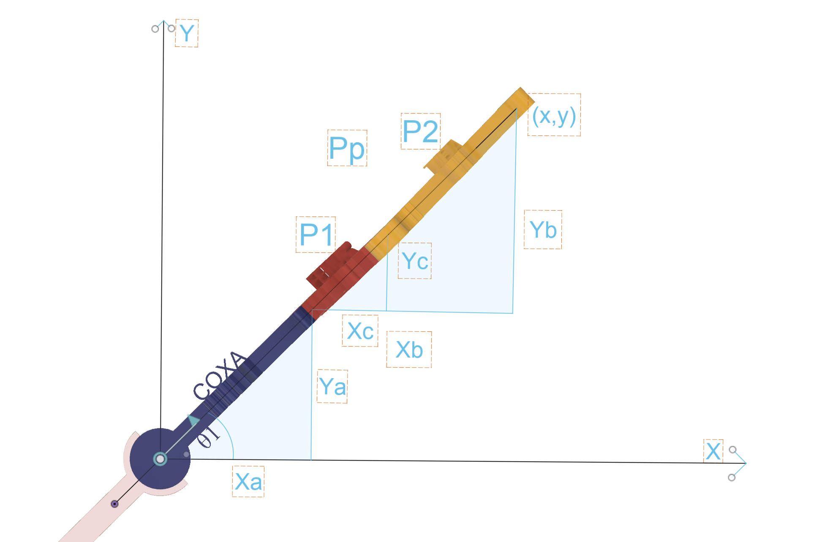
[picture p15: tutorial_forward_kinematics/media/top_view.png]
Spider robot leg top view

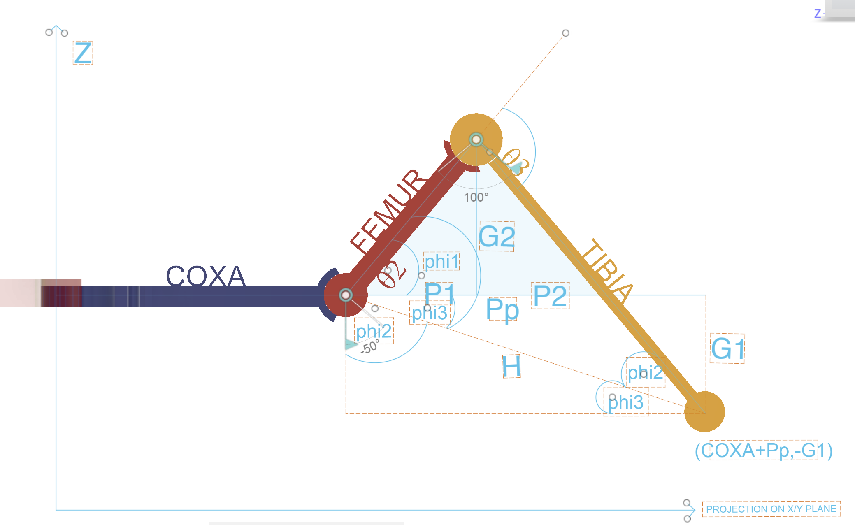
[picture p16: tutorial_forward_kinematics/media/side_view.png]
Spider robot leg side view

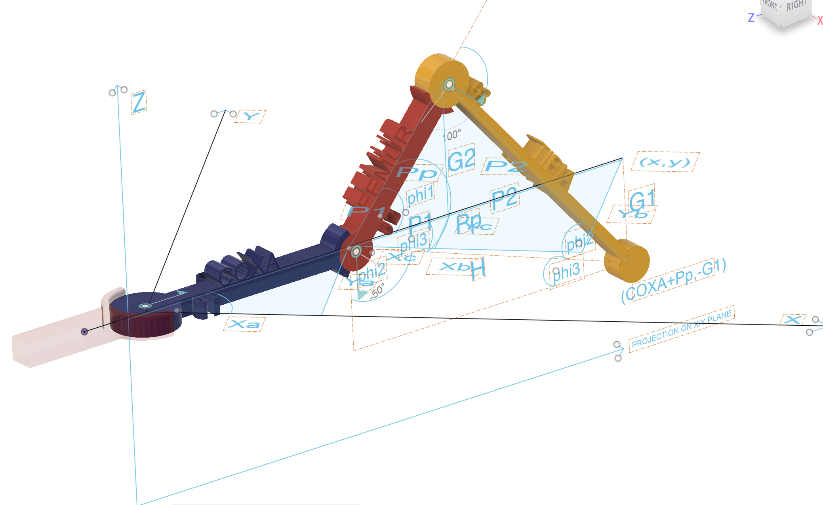
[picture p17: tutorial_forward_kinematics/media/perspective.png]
Spider robot leg perspective


1. **Angle Conversion**:
   The method begins by converting the joint angles from degrees to radians. This conversion is essential as trigonometric functions in Python's math library require angles in radians.

   ```python
   theta1, theta2, theta3 = map(math.radians, self.get_angles())
   ```

2. **Coxa-Femur Joint Calculation**:
   - `Xa` and `Ya` determine the x and y coordinates of the coxa-femur joint (the hip joint). They are calculated using the cosine and sine of `theta1`, respectively, multiplied by the length of the coxa (`self.COXA`). Cosine gives the horizontal component, and sine provides the vertical component.

     ```python
     Xa = self.COXA * math.cos(theta1)
     Ya = self.COXA * math.sin(theta1)
     ```

3. **Femur Segment Calculations**:
   - The vertical component `G2` of the femur length is calculated by the femur length (`self.FEMUR`) multiplied by the sine of `theta2`. This gives the vertical displacement.
   - The horizontal component `P1` is found by multiplying the femur length by the cosine of `theta2`. This gives the horizontal displacement.

     ```python
     G2 = math.sin(theta2) * self.FEMUR
     P1 = math.cos(theta2) * self.FEMUR
     ```

4. **Femur-Tibia Joint Calculation**:
   - `Xc` and `Yc` are the x and y coordinates of the femur-tibia joint (knee joint), computed by multiplying `P1` with the cosine and sine of `theta1`.

     ```python
     Xc = math.cos(theta1) * P1
     Yc = math.sin(theta1) * P1
     ```

5. **Tibia-Tip Joint Calculation**:
   - This step involves calculating the position of the tibia-tip joint (foot of the leg) using a series of trigonometric calculations.
   - `H` is the straight-line distance from the femur-tibia joint to the tibia-tip joint, calculated using the Law of Cosines.

     ```python
     H = math.sqrt(self.TIBIA**2 + self.FEMUR**2 - 2*self.TIBIA*self.FEMUR*math.cos(math.radians(180) - theta3))
     ```

   - `phi1` is calculated using the Law of Cosines again, to find the angle at the femur-tibia joint.

     ```python
     phi1 = math.acos((self.FEMUR**2 + H**2 - self.TIBIA**2) / (2*self.FEMUR*H))
     ```

   - `phi2` is the angle at the tibia-tip joint. It's calculated by subtracting `phi1` and the external angle \( 180^\circ - \theta3 \) from 180 degrees.
   - `phi3` is an auxiliary angle, used to find the horizontal and vertical projections. It's calculated by subtracting `theta2` from `phi1`.

     ```python
     phi2 = math.radians(180) - (math.radians(180) - theta3) - phi1
     phi3 = phi1 - theta2
     ```

   - `Pp` is the horizontal projection of the tibia-tip joint on the plane of the femur. It is calculated using the cosine of `phi3` multiplied by `H`.

     ```python
     Pp = math.cos(phi3) * H
     ```

   - `P2` is the horizontal distance between the femur-tibia joint and the tibia-tip joint. It is calculated as the difference between `Pp` and `P1`.

     ```python
     P2 = Pp - P1
     ```

   - `Yb` and `Xb` are the x and y coordinates of the tibia-tip joint, calculated by multiplying the sine and cosine of `theta1` by `Pp`, respectively.

     ```python
     Yb = math.sin(theta1) * Pp
     Xb = math.cos(theta1) * Pp
     ```

   - `G1` is the vertical component (z-coordinate) of the tibia-tip joint. It is calculated using the sine of `phi3` multiplied by `H`. The result is negated as the z-axis might be defined downwards in the robot's coordinate system.

     ```python
     G1 = math.sin(phi3) * H
     G1 = -G1
     ```

6. **Joint Locations List**:
   - The method concludes by creating a list of joint locations. Each joint location is represented by a set of x, y, and z coordinates. This list includes the positions of the base joint, coxa-femur joint, femur-tibia joint, and the tip of the leg.

     ```python
     joint_locations = [
         [0, 0, 0],  # Base joint
         [Xa, Ya, 0],  # Coxa-femur joint
         [Xa + Xc, Ya + Yc, G2],  # Femur-tibia joint
         [Xa + Xb, Ya + Yb, G1]  # Tip of the leg
     ]
     ```

>Remember, the beauty of robotics lies not just in the final product, but in the intricate processes that bring the robot to life. Happy coding!

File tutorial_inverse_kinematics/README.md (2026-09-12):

Read the companion tutorial on [Catch IT](https://catchit.pl/): [Inverse Kinematics for a Hexapod Leg](https://catchit.pl/blog/inverse-kinematics-for-a-hexapod-leg/).

> **Disclaimer:** This tutorial is part of a comprehensive series that I've created to guide you through the process of building a spider robot. Each tutorial in the series is designed to cover a specific aspect of the project, providing detailed instructions and insights to help you understand and replicate the steps.
> 
> You can find the entire series [here](../README.md). I encourage you to explore all the tutorials in the series to gain a complete understanding of the project. Whether you're following along to build your own spider robot, or simply interested in learning more about robotics, I hope you find these resources helpful and informative. Happy building!

## Inverse Kinematics for Spider Robot Legs

Hello, fellow code explorers and welcome to the next episode of 'Rob's Tech Workbench'! I'm your host, Robert Meisner, and I'm thrilled to invite you on a captivating journey as we build a mesmerizing spider robot from scratch! 

Now, if you think that I'm new to this realm, you're absolutely right! This is my first time tackling such a complex robotics project from scratch, but worry not, because together we'll learn, grow, and overcome every challenge that comes our way. Throughout this series, we'll be diving into fascinating topics such as mechanical design, electronics, coding, and much more.

Today's enchanting adventure begins with exploring the secrets of Inverse Kinematics, where we'll learn how our spider robot will move its legs to traverse its surroundings gracefully.
 Are you ready to embark on this fantastical voyage? 
 If so, then buckle up, hit that like button, and let's get started!"

## Resources

This repository includes a [Jupyter Notebook](inverse_kinematics_code.ipynb) that contains the code and visualizations for the inverse kinematics tutorial. 

Additionally, a [Fusion 360 file](Hexapod_Leg_Fusion360.f3d) is provided for a 3D model of the hexapod leg, which can be used for visualization and further exploration of the problem.

# Inverse Kinematics for a Spider Robot Leg

In this tutorial, we'll learn how to write a `SpiderLeg` class to perform 
inverse kinematics calculations for a spider robot leg. 
We'll start by discussing the knowledge needed, such as trigonometry, 
and then we'll dive into the implementation details with examples. 

I was inspired by the MakeYourPet project. [The MakeYourPet](https://github.com/MakeYourPet/hexapod) project is an excellent resource for anyone interested in building a hexapod robot at home using a 3D printer and some basic components. The creators of the project provide all the necessary software, STL files, and a detailed description of the electronic components required to assemble the hexapod. They also offer step-by-step instructions on how to put everything together and control the hexapod using an old Android phone.

The MakeYourPet project is ideal for those who want to build a hexapod without getting too deep into the complexities of robotics.
The community behind the project is supportive and can help you through any challenges you might encounter during the build process. If you're interested in building your own hexapod, I highly recommend checking out the MakeYourPet GitHub repository and joining their Discord server for guidance and support.

## Prerequisites

Before we get started, make sure you have a basic understanding of the following concepts:

1. High school trigonometry (projections, sine, cosine, tangent, and their inverse functions)
2. Coordinate systems (Cartesian and polar)
3. Vectors and vector operations
4. Basic programming concepts (variables, functions, loops, and conditional statements)

## Inverse Kinematics

Inverse kinematics is a method used in robotics to calculate 
the joint angles required to achieve a specific target position in the workspace. 
The opposite of inverse kinematics is forward kinematics, 
which calculates the position of the end effector (e.g., the tip of a robot arm or leg) given the joint angles.

In the case of our spider robot leg, we have three joints: the coxa (hip), femur (thigh), and tibia (shin). 
Each joint has an associated angle, which we'll call `theta1`, `theta2`, and `theta3`. Our goal is to determine the values of these angles that will place the leg's end effector (the foot) at a desired target position `(x, y, z)`.

## The SpiderLeg Class

Now that we have a basic understanding of inverse kinematics, let's dive into the implementation of the `SpiderLeg` class. The class will handle the following tasks:

1. Store the leg's joint angles and segment lengths (coxa, femur, and tibia)
2. Calculate the inverse kinematics to determine the joint angles required to reach a target position
3. Calculate the forward kinematics to determine the end effector position given the joint angles
4. Normalize joint angles to the [-180, 180] degree range

```python
class SpiderLeg:
    def __init__(self, name, COXA, FEMUR, TIBIA):
        self.name = name
        self.COXA = COXA
        self.FEMUR = FEMUR
        self.TIBIA = TIBIA
        self.theta1 = 0.
        self.theta2 = 0.
        self.theta3 = 0.
        self.joints = self.forwardKinematics()

    def inverseKinematics(self, target=None):
        # Your inverse kinematics implementation here
        pass

    def forwardKinematics(self, angles=None):
        # Your forward kinematics implementation here
        pass
```

In the example above, we have defined a simplified SpiderLeg class that represents a single leg of a spider robot. The class includes the following elements:

The __init__ method initializes the class with a name, segment lengths (COXA, FEMUR, and TIBIA), and initial joint angles (theta1, theta2, and theta3). The forwardKinematics method is called to calculate the initial joint positions.

The inverseKinematics method is a placeholder for the actual implementation of inverse kinematics calculations. When given a target position, this method should compute the joint angles (theta1, theta2, and theta3) required to reach the target.

The forwardKinematics method is a placeholder for the actual implementation of forward kinematics calculations. When given a set of joint angles (theta1, theta2, and theta3), this method should calculate the resulting end-effector (foot) position in the 3D space.

This simplified structure provides a foundation for implementing the inverse and forward kinematics algorithms. You can extend the class by adding more functionality, such as methods to control the servos, update the joint angles, or visualize the leg movement.

## Disclaimers

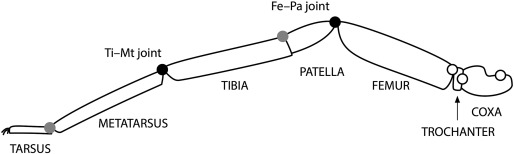
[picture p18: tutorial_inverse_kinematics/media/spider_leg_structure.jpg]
Spider leg structure
Before we dive into the explanation of the spider leg model, it's important to note that the actual structure and movement of a spider leg in nature are far more complex than our simplified representation. In this tutorial, we are using a basic mechanical model with three segments and three joint angles to help us understand the fundamental concepts of leg movement and inverse kinematics. Keep in mind that real spider legs have more intricate joint structures, muscle systems, and movement patterns, and our model serves as an approximation for educational purposes. 

Please also note that the approach presented in this tutorial is a simplified, naive method for solving inverse kinematics. In robotics and more advanced applications, there are more sophisticated methods used for inverse kinematics, such as the Denavit-Hartenberg (D-H) method, the Jacobian method, or the Cyclic Coordinate Descent (CCD) method. These methods offer more accurate and efficient ways to solve inverse kinematics, especially for more complex robotic systems. However, for the purpose of this tutorial and for a better understanding of the basic concepts, I have chosen a simplified approach.

## Understanding the Geometry:Perspective Views, Top and Side

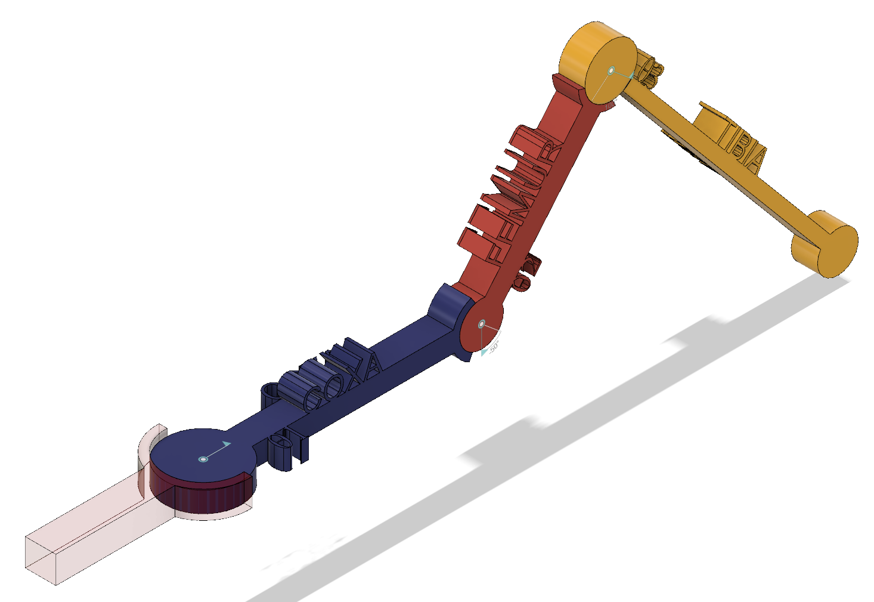
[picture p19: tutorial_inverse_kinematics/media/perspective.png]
The leg is composed of three main segments: the coxa, femur, and tibia


In this perspective view of the spider leg, we can appreciate the overall leg structure and the relationships between its components. The leg is composed of three main segments: the coxa, femur, and tibia. Each segment connects to another at a joint, allowing the leg to move in a coordinated manner.

The coxa is the first segment, connecting the leg to the spider's body. It is responsible for the leg's horizontal rotation, controlled by the angle θ1. Moving on from the coxa, we have the femur segment. The femur is the second, longer segment, which primarily controls the leg's vertical movement. Finally, we have the tibia, the third segment, which extends or retracts the leg in relation to the femur.

To better understand how these segments work together, let's take a closer look at angle θ1. As mentioned earlier, θ1 determines the horizontal orientation of the leg. It is the angle between the coxa and the X-axis, controlling the leg's rotation on a horizontal plane.
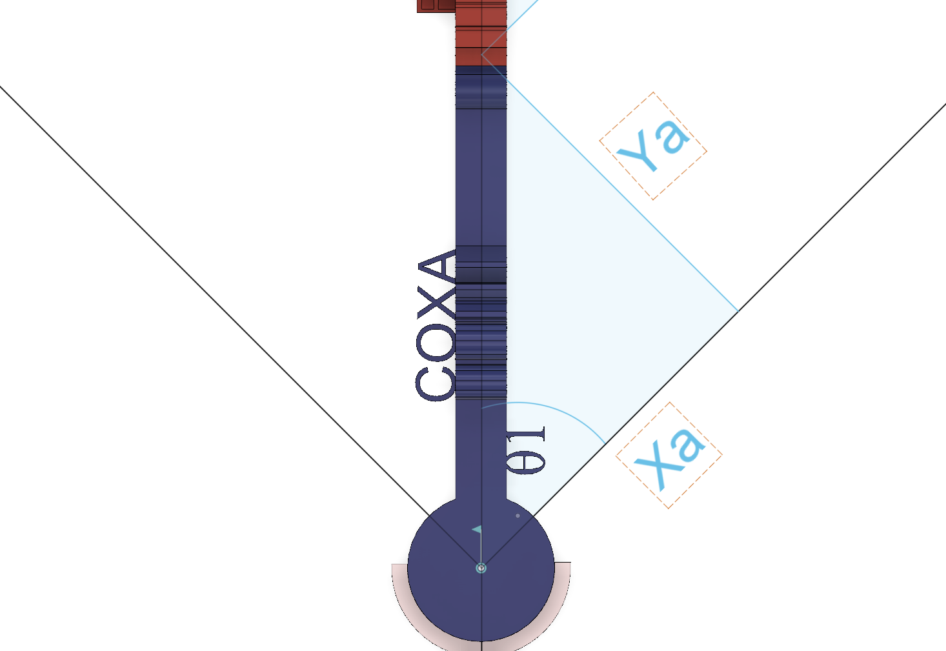
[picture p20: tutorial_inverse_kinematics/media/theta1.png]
Theta1 angle of the leg


θ2 is the angle at the coxa-femur joint, which determines the leg's vertical position. It is responsible for raising or lowering the leg and is mainly influenced by the femur segment's length and orientation.
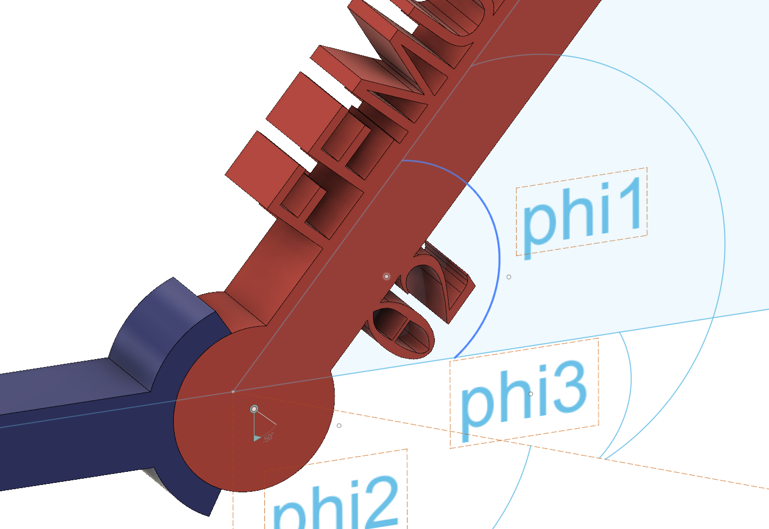
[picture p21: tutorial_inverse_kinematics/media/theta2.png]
Theta2 angle of the leg


θ3 is the angle between the femur and tibia segments. It controls the leg's extension or retraction, allowing the spider to reach farther or pull the leg closer to its body. This angle is essential for adjusting the leg's position and maintaining stability during movement.
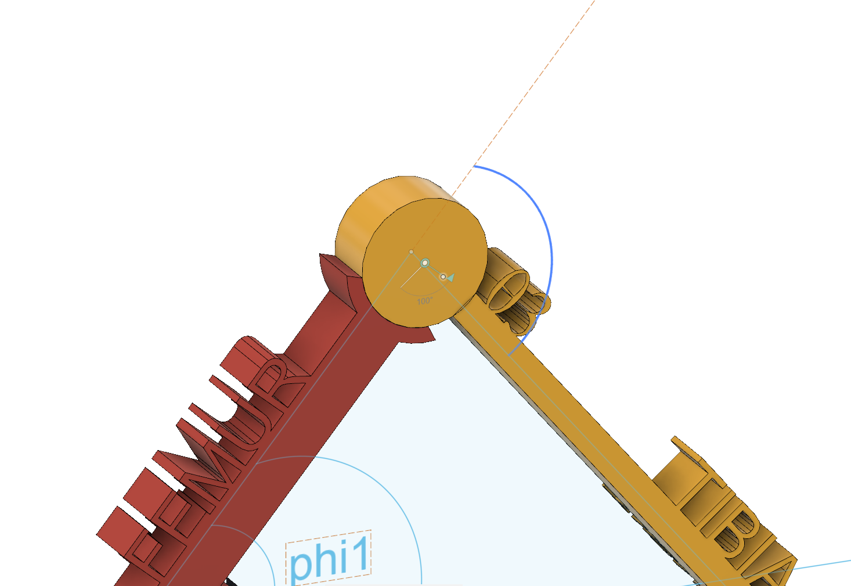
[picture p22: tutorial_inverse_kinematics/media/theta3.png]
Theta3 angle of the leg


By understanding the relationships between the coxa, femur, tibia, and the angles θ1, θ2, and θ3, we can better appreciate the complex yet elegant kinematics of a spider leg and how inverse kinematics can be used to calculate the necessary joint angles for achieving specific leg positions.

Alright, now let's have a look at the top view of the spider leg. 
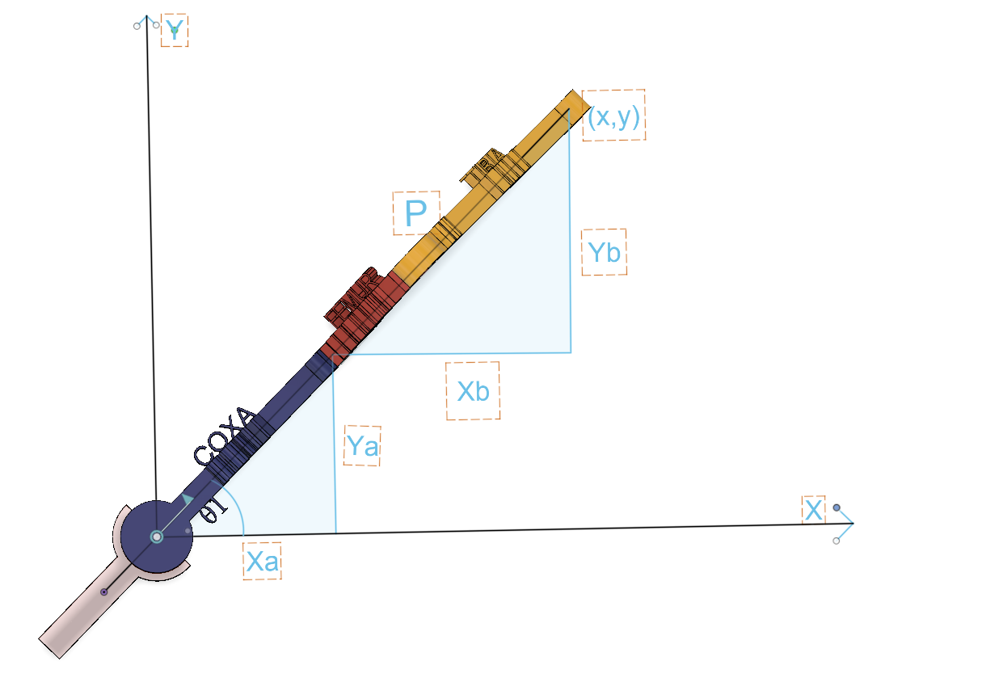
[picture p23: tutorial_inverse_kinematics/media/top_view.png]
Top view of the spider leg

From this perspective, we can clearly see how the leg extends horizontally on the X-Y plane. 
From this top view, we can observe how the joint angle θ1 determines the leg's position in the X-Y plane. 
Keep in mind that θ1 is the angle between the coxa and the X-axis. 
The other joint angles, θ2 and θ3, which control the orientation of the femur and tibia segments, are not visible from the top view.
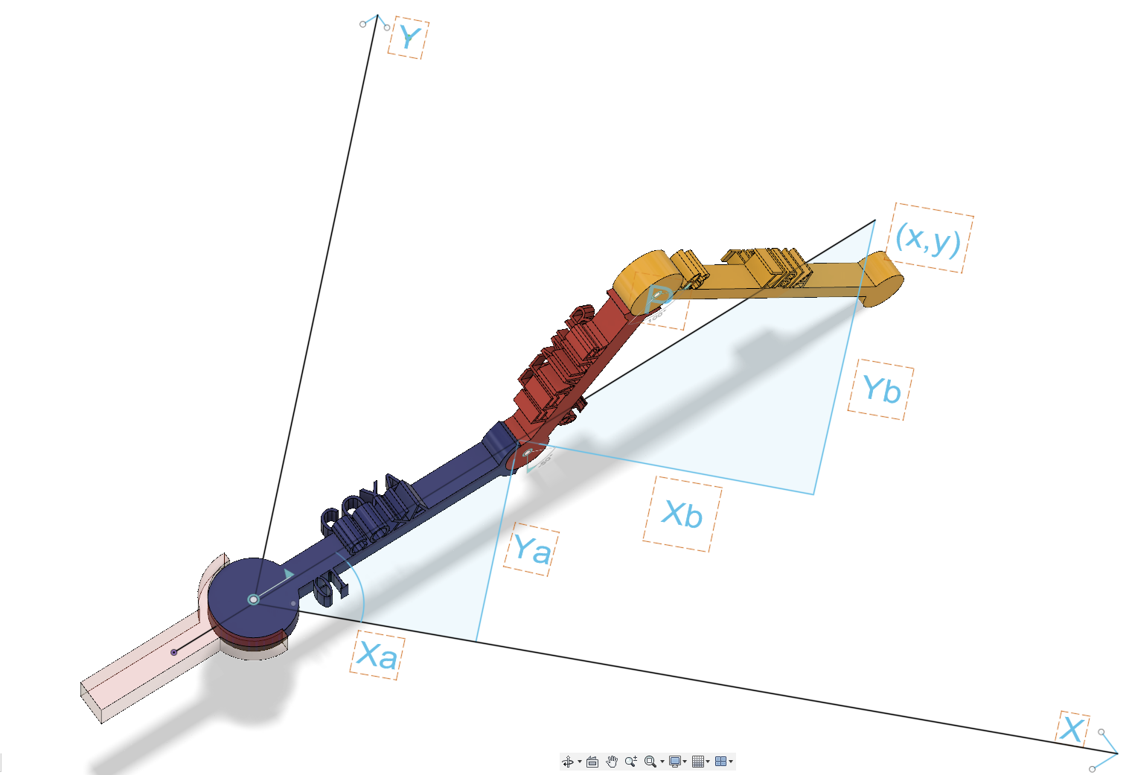
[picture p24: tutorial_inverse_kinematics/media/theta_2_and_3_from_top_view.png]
theta2 and 3 from the top view


In this view, we can also see some of the auxiliary variables we will use to calculate θ2 and θ3. 
Specifically, Xa and Ya represent the projections of the coxa segment along the X and Y axes, respectively. 
By calculating Xa and Ya, we can determine the starting point of the femur segment, which then helps us to calculate P, the projection of FEMUR and TIBIA on X/Y plane. 
Xb and Yb are the horizontal and vertical distances from the end of the COXA segment to the target point (x, y) in the X/Y plane.

Now let's move on to the side view, where we can better understand the roles of θ2, θ3, and the other variables.
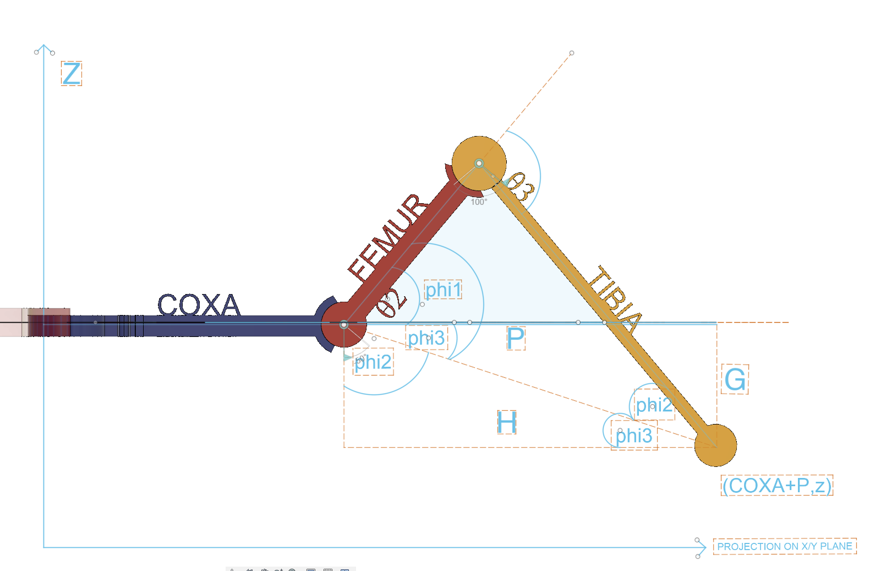
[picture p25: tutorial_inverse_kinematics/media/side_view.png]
Side view of the spider leg

In the side view, we can further analyze the relationship between θ2, θ3, and the leg segments, along with the auxiliary variables H, G, P, phi1, phi2, and phi3.
First, let's look at H, G, and P. 

G is the absolute value of the Z coordinate, representing the vertical distance between the coxa-femur joint and the target position. 
P, as mentioned earlier, is the projection of FEMUR and TIBIA on X/Y plane.
H is the length of the hypotenuse of a right-angled triangle formed by P and G. 

Now let's discuss phi1, phi2, and phi3. 
These angles are used as intermediate steps in calculating θ2 and θ3. 
Phi1 is the angle formed by the femur, and H, while phi2 is the angle between the tibia and H. 
Phi3 is the angle between the projection P on horizontal plane (formed by the X and Y axes) and H.

I chose the angles phi1, phi2, and phi3 to assist in calculating the theta angles for our spider leg. These angles were specifically chosen because they help us break down the problem into manageable parts, using well-known trigonometric functions and rules.
It's important to note that you can choose other angles or methods to calculate the theta angles, depending on your specific problem or the way you want to approach the inverse kinematics. The key is to find an approach that makes the calculations more straightforward and easier to understand.
In our case, we used phi1, phi2, and phi3 because they allowed us to form right-angled triangles and apply trigonometric functions like sine, cosine, and tangent. This made it easier to calculate the required joint angles for the spider leg. Remember, the goal is to find an approach that works for your specific problem and makes the calculations more manageable.

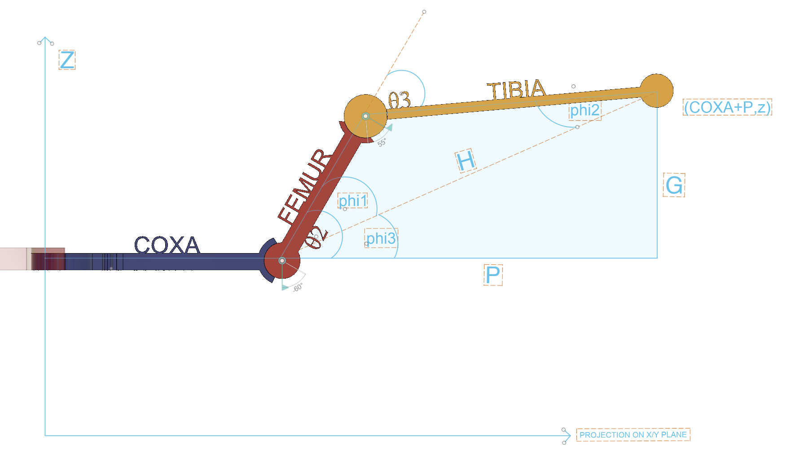
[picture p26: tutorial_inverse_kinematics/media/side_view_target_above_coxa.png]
Side view with the target above the coxa

From the side view, we can observe how θ2 and θ3 control the leg's vertical position and extension. 
θ2 is primarily responsible for the leg's vertical movement, while θ3 controls the leg's extension or retraction in relation to the femur. 
By understanding the relationships between these angles and the auxiliary variables, we can gain a deeper insight into the spider leg's kinematics and the role of inverse kinematics in achieving the desired leg positions.

Now that we have a good understanding of the spider leg's structure from different views, let's dive into the calculation process that helps us determine the required joint angles to reach a specific target position. 
This process, known as inverse kinematics, is crucial for simulating the movement of the spider leg and controlling it in a precise manner.

In the next section, we will explore the mathematical concepts and trigonometric formulas that play a key role in solving the inverse kinematics problem for our spider leg model. 
We will break down each step of the calculation process, explaining the reasoning behind the use of specific trigonometric functions and rules. 
Even if you're not familiar with trigonometry, don't worry! We'll make sure to explain everything in a way that is easy to understand and follow.

So, get ready to dive into the fascinating world of inverse kinematics and see how mathematics can bring our simplified spider leg to life!

## Basic Trigonometry and Triangular Laws Review

First, let's recall some basic trigonometric functions and rules:

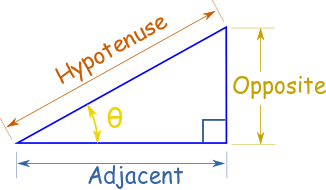
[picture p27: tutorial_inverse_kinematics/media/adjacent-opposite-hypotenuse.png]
Triangle hypotenuse,opposite,adjacent


**Sine (sin)** - The ratio of the length of the side opposite the angle to the length of the hypotenuse in a right-angled triangle.
$$sin(\theta)=\frac{opposite}{hypotenuse}$$
To calculate the actual angle using sine, you will need to use the inverse sine function, also known as arcsine ($sin^-1$ or asin). 
The arcsine function helps you find the angle when you know the sine value. 
The formula for finding the angle using arcsine is:
$$\theta = arcsin(\frac{opposite}{hypotenuse})$$

**Cosine (cos)** - The cosine of an angle in a right-angled triangle is defined as the ratio of the length of the adjacent side to the length of the hypotenuse. 
Mathematically, it can be represented as:
$$cos(\theta) = \frac{adjacent}{hypotenuse}$$
To calculate the actual angle using cosine, you will need to use the inverse cosine function, also known as arccosine (cos^(-1) or acos). 
The arccosine function helps you find the angle when you know the cosine value. 
The formula for finding the angle using arccosine is:
$$\theta = arccos(\frac{adjacent}{hypotenuse})$$

**Tangent (tan)** - The tangent of an angle in a right-angled triangle is defined as the ratio of the length of the opposite side to the length of the adjacent side. 
Mathematically, it can be represented as:
$$tan(\theta) = \frac{opposite}{adjacent}$$
To calculate the actual angle using tangent, you will need to use the inverse tangent function, also known as arctangent (tan^(-1) or atan). 
The arctangent function helps you find the angle when you know the tangent value. 
The formula for finding the angle using arctangent is:
$$\theta = arctan(\frac{opposite}{adjacent})$$

Now, let's discuss the **cosine rule**, also known as the **law of cosines**. The cosine rule applies to any triangle, not just right-angled triangles. 
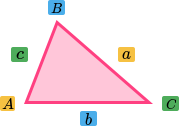
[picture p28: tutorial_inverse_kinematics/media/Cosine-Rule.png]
Cosine Rule


It relates the lengths of the sides of a triangle to the cosine of one of its angles. 
Given a triangle with sides a, b, and c and angles A, B, and C opposite those sides, the cosine rule states:

$$c^2 = a^2 + b^2 - 2ab \cdot cos(C)$$
$$b^2 = a^2 + c^2 - 2ac \cdot cos(B)$$
$$a^2 = b^2 + c^2 - 2bc \cdot cos(A)$$

These equations can be used to find the length of an unknown side when you know the lengths of the other two sides and the size of the angle between them. They can also be used to find the size of an angle when you know the lengths of all three sides.

The Side-Side-Side (SSS) Triangle is the triangle where all three sides are known.
In this case, you can use the cosine rule (law of cosines) to find the angles of the triangle. 
Given a triangle with sides a, b, and c, you can find the angles (capital letter) A, B, and C as follows:

Side-Side-Side (SSS) Triangle Rule

Use the cosine rule to find angle A:
$$cos(A) = \frac{b^2 + c^2 - a^2}{2bc}$$
$$A = arccos(\frac{b^2 + c^2 - a^2}{2bc})$$

Use the cosine rule to find angle B:
$$cos(B) = \frac{a^2 + c^2 - b^2}{2ac}$$
$$B = arccos(\frac{a^2 + c^2 - b^2}{2ac})$$

Since the sum of the angles in a triangle is always 180 degrees, you can find angle C:
$$C = 180^{\circ} - A - B$$

## Inverse Kinematics: Calculation Process
In this tutorial, we use two sets of symbols: theta (θ) and phi (φ). 
Both symbols represent angles, but they have different roles in the context of our leg kinematics.

Now, let's begin the process by calculating the first angle, θ1, which determines the leg's horizontal orientation. 
We need to find the angle between the coxa and the X-axis. 
To do this, we can imagine a right-angled triangle formed by the X and Y axes and the coxa. 
The coxa connects the origin (0,0) to the point (x, y), with x and y representing the coordinates of the endpoint in the top view.
Top view of the spider leg
In this right-angled triangle, the legs along the X and Y axes have lengths x and y, respectively. 
We need to find the angle between the X-axis and the coxa, which we can call θ1. 
To do this, we'll use the arctangent (atan) function, which is the inverse of the tangent function.

To determine the actual angle, θ1, we use the arctangent function (often abbreviated as atan). This mathematical tool calculates the angle when you know the ratio of the opposite side's length to the adjacent side's length in a right-angled triangle. Essentially, it helps us figure out the steepness or incline angle based on the triangle's dimensions.
In our case, the opposite side has a length of y, and the adjacent side has a length of x:
$$tan(\theta1)=\frac{y}{x}$$
 
To find the actual angle, θ1, we need to use the inverse tangent function, also known as arctangent (atan). The arctangent function helps you find the angle when you know the tangent value. 
So, in our right-angled triangle with legs x and y, atan2(y, x) gives the angle θ1 between the X-axis and the coxa. Unlike plain atan(y/x), atan2 also keeps track of the quadrant and works when x is zero:
```python
theta1 = atan2(y, x)
```
This calculation gives us the horizontal orientation of the leg, which is an essential first step in determining the joint angles for inverse kinematics.

Next, we'll calculate intermediate values needed for determining θ2 and θ3. 
We'll use the sine and cosine functions to find the lengths Xa and Ya, which are the projections of the coxa segment along the X and Y axes:
```python
Xa = COXA * cos((theta1))
Ya = COXA * sin((theta1))
```

Now, we'll find Xb and Yb, which are the remaining distances along the X and Y axes from the coxa segment to the target position:
```python
Xb = x - Xa
Yb = y - Ya
```
To find P, we can use the following relationship based on the cosine function for a right-angled triangle:
$$cos(\theta1) = \frac{adjacent}{hypotenuse}$$
In our case, the adjacent side is Xb, and the hypotenuse is P. 
Rearranging the equation, we get:
$$hypotenuse (P) = \frac{adjacent (Xb)}{cos(\theta1)}$$
Thus, the code:
```python
P = sqrt(Xb ** 2 + Yb ** 2)
```
calculates the hypotenuse P by the Pythagorean theorem — the same value as Xb / cos(θ1), but numerically stable also when the leg points straight along the Y axis and cos(θ1) is zero. P is the horizontal distance from the end of the coxa to the target point in the horizontal plane.

G is the absolute value of the z-coordinate of the target position. 
It represents the vertical distance between the coxa-femur joint and the target position along the z-axis.

We can imagine a right-angled triangle with P as the base (adjacent side), G as the height (opposite side), and H as the hypotenuse. In this triangle, the angle between the base (P) and the height (G) is a right angle (90 degrees).
The Pythagorean theorem states that in a right-angled triangle, the square of the length of the hypotenuse (the side opposite the right angle) is equal to the sum of the squares of the lengths of the other two sides. Mathematically, this can be written as:
$$H^2 = P^2 + G^2$$
To find the length of H, we can take the square root of both sides of the equation:
$$H = sqrt(P^2 + G^2)$$
```python
G = abs(z)
H = sqrt(P ** 2 + G ** 2)
```

We'll use the arcsine (asin) function, which is the inverse of the sine function, to find the angle φ3. In a right-angled triangle with legs G and H, the asin(G/H) gives the angle between the side opposite the angle and the hypotenuse:

```python
phi3 = asin(G / H)
```
Now, we'll apply the cosine rule to find the angles φ1 and φ2. The cosine rule is a formula that relates the lengths of the sides of a triangle to the cosine of one of its angles:
$$c^2 = a^2 + b^2 - 2ab * cos(C)$$

We'll rearrange the formula to find the cosine of angle C:
$$cos(C) = (a^2 + b^2 - c^2) / (2ab)$$

In our case, for φ2, a = self.TIBIA, b = H, and c = self.FEMUR:

```python
phi2Acos = ((self.TIBIA ** 2) + (H ** 2) - (self.FEMUR ** 2)) / (2 * self.TIBIA * H)
phi2 = acos(phi2Acos)
```

For φ1, a = self.FEMUR, b = H, and c = self.TIBIA:

```python
phi1 = acos((self.FEMUR ** 2 + H ** 2 - self.TIBIA ** 2) / (2 * self.FEMUR * H))
```
With the φ1, φ2, and φ3 values calculated, we can now determine θ2 and θ3 based on these values and the sign of z. 

**When the leg is lifted above the coxa (z > 0):**
In this case, the target position is above the coxa-femur joint along the z-axis. To reach this position, the leg needs to bend backward, which means theta2 should be positive. To calculate the correct value of theta2, we need to consider both phi1 and phi3. Since both angles are positive, we add them together:
theta2 = phi1 + phi3
Side view with the target above the coxa
**When the leg is lowered below the coxa (z ≤ 0):**
In this case, the target position is below the coxa-femur joint along the z-axis. To reach this position, the leg needs to bend forward, which means theta2 should be negative or smaller than phi1. To calculate the correct value of theta2, we need to consider the effect of phi3. Since phi3 is positive, we subtract it from phi1:
theta2 = phi1 - phi3
Side view of the spider leg
```python
if z > 0:
    theta2 = phi1 + phi3
else:
    theta2 = phi1 - phi3
```

Finally, we'll calculate θ3 as the sum of φ1 and φ2:

```python
theta3 = phi1 + phi2
```

With the angles θ1, θ2, and θ3 calculated, we can update the joint angles:

```python
ang = [degrees(theta1), degrees(theta2), degrees(theta3)]
self.setAngles(ang)
return ang
```

To summarize, we've used trigonometric functions such as sine, cosine, and tangent, as well as the cosine rule, to calculate the joint angles required for our spider leg model to reach a specific target position. By understanding the relationships between the lengths and angles in right-angled triangles, we've been able to apply these principles to a more complex, three-dimensional problem.

## Resources and Links: GitHub Repository and 3D Fusion 360 Model
If you want to dive deeper into the topic or play around with the code and visualization, we've got you covered! 
The complete Jupyter Notebook with all the code and visualizations we discussed today is available on our GitHub repository. You can find the link in the description below.

In addition to the code, I've also created a detailed 3D model of the spider leg using Autodesk Fusion 360. 
This model will help you better understand the structure, movement, and the various components we discussed in this tutorial. 
You can access the 3D model through the link provided in the description below.

Happy coding!

## Ending word
And there you have it, everyone! I really enjoyed creating this video for you, and I hope it has helped you understand the workings of a simplified spider leg model and the trigonometry behind it. 
I'm always looking forward to hearing your thoughts, so if you found this video helpful or have any suggestions for what you'd like me to cover next, please leave a comment below. Your feedback will help me create better content for you in the future. 
Remember to like this video, share it with your friends, and subscribe to my channel for more educational content like this. Thanks for watching, and until next time, happy learning!

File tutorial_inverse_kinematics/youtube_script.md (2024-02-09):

Today's enchanting adventure begins with exploring the secrets of Inverse Kinematics, where we'll learn how our spider robot will move its legs to traverse its surroundings gracefully.

In this tutorial, we'll learn how to write a `SpiderLeg` class to perform 
inverse kinematics calculations for a spider robot leg. 
Inverse kinematics is a method used in robotics to calculate 
the joint angles required to achieve a specific target position in the workspace. 
The opposite of inverse kinematics is forward kinematics, 
which calculates the position of the end effector (for example the tip of a robot arm or leg) given the joint angles.
In the case of our spider robot leg, we have three joints: the coxa (hip), femur (thigh), and tibia (shin). 
Each joint has an associated angle, which we'll call `theta1`, `theta2`, and `theta3`. Our goal is to determine the values of these angles that will place the leg's end effector (the foot) at a desired target position `(x, y, z)`.

```python

class SpiderLeg:
    def __init__(self, name, COXA, FEMUR, TIBIA):
        self.name = name
        self.COXA = COXA
        self.FEMUR = FEMUR
        self.TIBIA = TIBIA
        self.theta1 = 0.
        self.theta2 = 0.
        self.theta3 = 0.
        self.joints = self.forwardKinematics()

    def inverseKinematics(self, target=None):
        # Your inverse kinematics implementation here
        pass

    def forwardKinematics(self, angles=None):
        # Your forward kinematics implementation here
        pass

```

In the example above, we have defined a simplified SpiderLeg class that represents a single leg of a spider robot. The class includes the following elements:

The "init" method initializes the class with a name, segment lengths (COXA, FEMUR, and TIBIA), and initial joint angles (theta1, theta2, and theta3). The forwardKinematics method is called to calculate the initial joint positions.

The inverseKinematics method is a placeholder for the actual implementation of inverse kinematics calculations. When given a target position, this method should compute the joint angles (theta1, theta2, and theta3) required to reach the target.

The forwardKinematics method is a placeholder for the actual implementation of forward kinematics calculations. When given a set of joint angles (theta1, theta2, and theta3), this method should calculate the resulting end-effector (foot) position in the 3D space.

This simplified structure provides a foundation for implementing the inverse and forward kinematics algorithms. You can extend the class by adding more functionality, such as methods to control the servos, update the joint angles, or visualize the leg movement.

First, let's delve into the fascinating geometry of a spider leg, comprising three primary segments: the coxa, femur, and tibia. Each joint's movement is governed by angles theta1, theta2, and theta3, which dictate the leg's horizontal rotation, vertical movement, and extension, respectively. Exploring different views, like the top and side perspectives, helps us understand how each joint angle affects the leg's orientation in the X-Y plane and its overall positioning. However, this is just scratching the surface of the spider leg's complex kinematics. For a more in-depth understanding and to see the intricate interplay of these angles and segments, I highly encourage you to visit my detailed tutorial on GitHub, where I break down the concepts further and provide a comprehensive guide to the sophisticated world of inverse kinematics.

Next, let's revisit fundamental trigonometric functions. Sine, co-sign, and tangent are crucial for understanding the angles and sides of right-angled triangles. We also dissect the co-sign rule, a pivotal principle that extends beyond right-angled triangles, helping us determine unknown sides and angles. These concepts are not just theoretical; they're the building blocks for calculating precise movements of our spider leg model. While these explanations provide a snapshot of the mathematical intricacies involved, I invite you to join me on GitHub again for a comprehensive breakdown. There, I unpack these concepts further, ensuring you have a robust foundation to tackle the complexities of inverse kinematics.

I apologize for the lengthy introduction, but it's essential for understanding what's to come. Now, let's move on to the actual calculation process and dive into the practical side of inverse kinematics. Thank you for your patience; let's get started!

## Inverse Kinematics: Calculation Proces

Now, let's begin the process by calculating the first angle, theta1, which determines the leg's horizontal orientation. 
To do this, we can imagine a right-angled triangle formed by the X and Y axes and the coxa. 

Top view of the spider leg
We need to find the angle between the X-axis and the coxa, which we can call theta1. 

To determine the actual angle, theta1, we use the arctangent function (often abbreviated as atan). This mathematical tool calculates the angle when you know the ratio of the opposite side's length to the adjacent side's length in a right-angled triangle. Essentially, it helps us figure out the steepness or incline angle based on the triangle's dimensions.
So, in our right-angled triangle with legs x and y, the atan(y/x) gives the angle theta1 between the X-axis and the coxa.
```python
theta1 = atan(y / x)
```
This calculation gives us the horizontal orientation of the leg, which is an essential first step in determining the joint angles for inverse kinematics.

Next, we'll calculate intermediate values needed for determining theta2 and theta3. 
We'll use the sign and co-sign functions to find the lengths Xa and Ya, which are the projections of the coxa segment along the X and Y axes.
```python
Xa = COXA * cos((theta1))
Ya = COXA * sin((theta1))
```

Now, we'll find X-b and Y-b, which are the remaining distances along the X and Y axes from the coxa segment to the target position:
```python
Xb = x - Xa
Yb = y - Ya
```
To find P, we can use the following relationship based on the co-sign function for a right-angled triangle:
$$cos(\theta1) = \frac{adjacent}{hypotenuse}$$
In our case, the adjacent side is Xb, and the hypotenuse is P. 
Rearranging the equation, we get:
$$hypotenuse (P) = \frac{adjacent (Xb)}{cos(\theta1)}$$
Which we translate to python code that calculates the hypotenuse P, which is the horizontal distance from the end of the coxa to the target point in the horizontal plane.
```python
P = Xb / cos(theta1)
```

G is the absolute value of the z-coordinate of the target position. 
It represents the vertical distance between the coxa-femur joint and the target position along the z-axis.

We can imagine a right-angled triangle with P as the base (adjacent side), G as the height (opposite side), and H as the hypotenuse. In this triangle, the angle between the base (P) and the height (G) is a right angle (90 degrees).
The Pythagorean theorem states that in a right-angled triangle, the square of the length of the hypotenuse (the side opposite the right angle) is equal to the sum of the squares of the lengths of the other two sides. 

$$H^2 = P^2 + G^2$$
To find the length of H, we can take the square root of both sides of the equation.
$$H = sqrt(P^2 + G^2)$$
```python
G = abs(z)
H = sqrt(P ** 2 + G ** 2)
```

Next we'll use the arcsine (asin) function, which is the inverse of the sine function, to find the angle phi3. In a right-angled triangle with legs G and H, the arcsine G over H gives the angle between the side opposite the angle and the hypotenuse.

```python
phi3 = asin(G / H)
```
Now, we'll apply the co-sign rule to find the angles phi1 and phi2. The co-sign rule is a formula that relates the lengths of the sides of a triangle to the co-sign of one of its angles:
$$c^2 = a^2 + b^2 - 2ab * cos(C)$$

We'll rearrange the formula to find the co-sign of angle C.
$$cos(C) = (a^2 + b^2 - c^2) / (2ab)$$

In our case, for phi2, a = self.TIBIA, b = H, and c = self.FEMUR:

```python
phi2Acos = ((self.TIBIA ** 2) + (H ** 2) - (self.FEMUR ** 2)) / (2 * self.TIBIA * H)
phi2 = acos(phi2Acos)
```

For phi1, a = self.FEMUR, b = H, and c = self.TIBIA:

```python
phi1 = acos((self.FEMUR ** 2 + H ** 2 - self.TIBIA ** 2) / (2 * self.FEMUR * H))
```
With the phi1, phi2, and phi3 values calculated, we can now determine theta2 and theta3 based on these values and the sign of z. 

When the leg is lifted above the coxa (z is larger than 0)
In this case, the target position is above the coxa-femur joint along the z-axis. To reach this position, the leg needs to bend backward. To calculate the correct value of theta2, we need to consider both phi1 and phi3. We add them together:
theta2 = phi1 + phi3
Top view of the spider leg
When the leg is lowered below the coxa (z ≤ 0):
In this case, the target position is below the coxa-femur joint along the z-axis. To calculate the correct value of theta2, we need to consider the effect of phi3. 
Top view of the spider leg
```python
if z > 0:
    theta2 = phi1 + phi3
else:
    theta2 = phi1 - phi3
```

Finally, we'll calculate theta3 as the sum of phi1 and phi2.

```python
theta3 = phi1 + phi2
```

With the angles theta1, theta2, and theta3 calculated, we can update the joint angles.

```python
ang = [degrees(theta1), degrees(theta2), degrees(theta3)]
self.setAngles(ang)
return ang
```

To summarize, we've used trigonometric functions such as sine, co-sign, and tangent, as well as the co-sign rule, to calculate the joint angles required for our spider leg model to reach a specific target position. By understanding the relationships between the lengths and angles in right-angled triangles, we've been able to apply these principles to a more complex, three-dimensional problem.

It's important to note that the actual structure and movement of a spider leg in nature are far more complex than our simplified representation. In this tutorial, we are using a basic mechanical model with three segments and three joint angles to help us understand the fundamental concepts of leg movement and inverse kinematics. Keep in mind that real spider legs have more intricate joint structures, muscle systems, and movement patterns, and our model serves as an approximation for educational purposes. Spider leg structure

Please also note that the approach presented in this tutorial is a simplified, you could say naive method for solving inverse kinematics. In robotics and more advanced applications, there are more sophisticated methods used for inverse anf forward kinematics, such as the Denavit-Hartenberg (D-H) method, the Jacobian method, or the Cyclic Coordinate Descent (CCD) method. These methods offer more accurate and efficient ways to solve inverse kinematics, especially for more complex robotic systems. However, for the purpose of this tutorial and for a better understanding of the basic concepts, I have chosen a simplified approach. If you want to learn more about those advanced topics strongly advise you to follow up with lectures of Angela Sodemann. You will find links to her lectures in the video description.

## Ending word
And there you have it! I really enjoyed creating this video for you, and I hope it has helped you understand the workings of a simplified spider leg model and the trigonometry behind it. 
I'm always looking forward to hearing your thoughts, so if you found this video helpful or have any suggestions for what you'd like me to cover next, please leave a comment below. Your feedback will help me create better content for you in the future. 
Remember to like this video, share it with your friends, and subscribe to my channel for more educational content like this. Thanks for watching, and until next time, happy learning!

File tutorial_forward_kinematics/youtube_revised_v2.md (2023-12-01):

[**Intro Music**]

**Narrator:** "Welcome, tech enthusiasts and future roboticists! You're tuning in to our comprehensive tutorial series on building a spider robot. Whether you're just starting out or leveling up your skills, this guide is here to make your journey an enlightening one."

[**Visual: Series Title and Disclaimer Slide**]

**Narrator:** "Before we start, don't forget to check out my other tutorials in this series for a rounded understanding of the project. Each tutorial is crafted to build your skills, step by step. Find the complete series in the description below."

[**Visual Transition: Opening Slide for Today's Tutorial**]

**Narrator:** "Today, we're focusing on a crucial aspect of robotic movement in our spider robot - the forward kinematics method. Let's break down this concept and see how it brings our robot to life."

[**Visual: Diagram of Spider Robot**]

**Narrator:** "Imagine each leg of our robot as a mini-chain of joints and segments. Forward kinematics is our tool to figure out where the tip of each leg will be, based on the angles of these joints. Think of it like predicting where your hand ends up when you move your arm, without looking."

[**Visual: Basic Trigonometry Slide**]

**Narrator:** "To understand this better, we need to touch upon some trigonometry basics. Trigonometry is all about angles and sides of triangles. Don't worry, we'll keep it simple."

[**Visual: Sine, co-sign, and Tangent Illustrations**]

**Narrator:** "First, the sine of an angle in a right-angled triangle is a ratio - the length of the side opposite the angle to the triangle's longest side, called the hypotenuse. co-sign is similar, but it's the side next to the angle over the hypotenuse. Tangent is the sine divided by the co-sign."

[**Visual: The Law of co-signs**]

**Narrator:** "Next, The Law of co-signs, a more generalized version of the Pythagorean theorem that applies to any triangle, not just right-angled ones. The Law of co-signs helps us relate the lengths of the sides of a triangle to the co-sign of one of its angles. It's particularly useful in robotics, where we often deal with non-right triangles formed by the robot's joints and limbs."

[**Visual: Transition to Spider Robot Leg Diagram**]

**Narrator:** "Now, let's apply these concepts to our spider robot's legs using the `forward_kinematics_naive` method."

[**Visual: Code Snippets and Leg Diagrams**]

**Narrator:** "We start by converting the angles of our robot's joints from degrees to radians. We use radians in these calculations because they provide a more natural way to describe angles in terms of their relation to the circle, which is essential in robotic movements."

[**Code Example: Angle Conversion**]

**Narrator:** "Next, we calculate the positions of each joint. Using sine and co-sign, we find the x and y coordinates for our robot's coxa joint, coxa-femur joint, and the femur-tibia joint."

[Visual: Highlighted Code Snippet]

Narrator: "First, we determine the x and y coordinates of the coxa-femur joint. This joint acts like the connection point in a human leg, linking the body to the upper leg segment."

[Visual: Illustration of Coxa-Femur Joint with Coordinates]

Narrator: "Using trigonometry, we calculate 'Xa', the horizontal position, and 'Ya', the vertical position, of this joint. We multiply the length of the coxa segment by the co-sign and sine of the coxa joint angle, respectively. This gives us precise coordinates based on our joint's current angle."

[Visual: Animated Calculation of Xa and Ya]

Narrator: "Next, we focus on the femur segment of our robot. We calculate its vertical and horizontal components. The vertical component, 'G2', is found by multiplying the femur's length by the sine of the coxa-femur joint angle, representing the vertical positioning of the femur-tibia joint."

[Visual: Illustration of Femur with Vertical Component]

Narrator: "Similarly, the horizontal component, 'P1', is the femur's length times the co-sign of the coxa-femur joint angle. This tells us the horizontal positioning of the femur-tibia joint relative to the coxa-femur joint."

[Visual: Animated Calculation of G2 and P1]

Narrator: "Finally, we calculate the x and y coordinates of the femur-tibia joint. By applying the horizontal component 'P1' to our previous calculations, we can pinpoint this joint's exact location in space."
**Narrator:** "The horizontal extension, 'X.c.', is determined by multiplying the length of the femur segment (represented by the horizontal component 'P1') by the co-sign of the coxa joint angle. This gives us the horizontal distance from the coxa-femur joint to the femur-tibia joint."

**Narrator:** "Similarly, the vertical extension, 'Y.c.', is found by multiplying the same femur length (the horizontal component 'P1') by the sine of the coxa joint angle. This calculation gives us the vertical distance from the coxa-femur joint to the femur-tibia joint."

[**Visual: Detailed Illustration of Spider Robot's Leg Joints**]

**Narrator:** "Let's focus on the femur-tibia joint, a key point in our leg's movement."

[**Visual: Illustration of the Femur, Tibia, and Angles**]

**Narrator:** "The Law of co-signs helps us find one side of a triangle when we know the other two sides and the angle between them. In our case, the sides are the lengths of the femur and tibia segments, and the angle is at the femur-tibia joint."

[**Visual: Equation of the Law of co-signs**]

**Narrator:** "Here's the formula: The square of the length of the side we want to find (the distance from the femur-tibia joint to the tibia tip) is equal to the sum of the squares of the femur and tibia lengths, minus twice their product multiplied by the co-sign of the angle at the femur-tibia joint. Mathematically, it looks like this."

[**Visual: Calculation Steps for H**]

**Narrator:** "By inputting the lengths of the femur and tibia, and the angle at the femur-tibia joint, we can solve for H, the straight-line distance from the femur-tibia joint to the tibia tip."

[**Visual: Breaking Down H into Horizontal and Vertical Components**]

**Narrator:** "With H known, our next task is to break this distance into horizontal and vertical components - this will give us the 'Xb' and 'Yb' coordinates of the femur-tibia joint. For this, we calculate additional angles at the coxa-femur and femur-tibia joints."

[**Visual: Trigonometric Formulas for Additional Angles**]

**Narrator:** "Using more trigonometry, we calculate these angles. We first find 'phi1', the angle at the coxa-femur joint, using the Law of co-signs again. This law helps us understand the relationship between H, the femur, and the tibia."

[**Visual: Equation for phi1**]

**Narrator:** "The formula for 'phi1' is \( \phi1 = \arccos\left(\frac{\text{FEMUR}^2 + H^2 - \text{TIBIA}^2}{2 \times \text{FEMUR} \times H}\right) \). This tells us the angle at the coxa-femur joint."

[**Visual: Calculation of  phi3**]

**Narrator:** "'phi3', an auxiliary angle, is then determined by subtracting the original angle at the coxa-femur joint from 'phi1'. These angles are crucial for determining the position of the femur-tibia joint."

[**Visual: Horizontal and Vertical Projections of H**]

**Narrator:** "Now, we use 'phi3' to find the horizontal projection 'P.p.' of the femur-tibia joint on the plane of the femur. This is calculated using the co-sign of 'phi3' multiplied by H. The horizontal distance between the coxa-femur joint and the femur-tibia joint, 'P2', is then the difference between 'P.p.' and the horizontal projection of the femur."

[**Visual: Final Calculation of Xb and Yb**]

**Narrator:** "Finally, we calculate 'Xb' and 'Yb', the x and y coordinates of the femur-tibia joint. These are found by using the sine and co-sign of the original coxa joint angle, multiplied by 'P.p.'. The vertical component of the femur-tibia joint, 'G1', is found using the sine of 'phi3' and H, and it might be negated depending on the robot's coordinate system orientation."

[**Visual: Overview of Joint Position Mapping**]

**Narrator:** "Now, let's connect the dots between our calculations and the robot's joint positions. Each of these intricate calculations - from the Law of co-signs to the determination of angles 'phi1', 'phi3' - plays a pivotal role in pinpointing the exact location of each joint in the robot's leg. The x and y coordinates we calculated for the coxa, coxa-femur, and femur-tibia joints - 'X.a.', 'Y.a.', 'X.b.', 'Y.b.', and so on - are more than just numbers; they represent the precise spatial coordinates where each joint should be positioned. By mapping these coordinates onto our robot, we can visualize and control the movement and articulation of each leg with incredible accuracy. This precise mapping is what allows our spider robot to move fluidly and respond accurately to our commands, making the journey from mathematical concepts to mechanical reality."

[Visual: 3D Animation of Spider Robot’s Leg]

Narrator: "With our calculations complete, it's time to bring our spider robot's leg to life in the virtual world. Let's see how we map out its joints in our code."

[Visual: Highlighted Code Snippet]

Narrator: "Here, we're creating a list that represents the locations of each joint in the leg. This list is the bridge between our mathematical calculations and the robot's physical structure."

[Visual: Animation Showing Joint Locations Being Added to List]

Narrator: "We start with the origin point, [0, 0, 0], the base from where our leg begins. Next, we add the coordinates of the coxa-femur joint, calculated earlier as 'X.a.' and 'Y.a.'. This joint is crucial as it connects the leg to the robot's body."

[Visual: Illustration of Coxa-Femur Joint with Coordinates]

Narrator: "Then, we move to the femur-tibia joint, crucial for leg articulation. By adding 'X.c.' and 'Y.c.' to our initial coxa-femur coordinates, and including the vertical component 'G2', we locate this joint precisely in three-dimensional space."

[Visual: Illustration of Femur-Tibia Joint with Coordinates]

Narrator: "Lastly, the endpoint of the leg, which interacts with the ground. Its coordinates are determined by adding 'Xb' and 'Yb' to the coxa-femur coordinates and using 'G1' as its vertical position. This marks the endpoint of our leg's journey."

**Narrator:** "And there you have it! By applying these trigonometric principles, we've precisely determined the position of the femur-tibia joint."

[**Outro Music**]

**Narrator:** "I hope this tutorial lit up your path in the fascinating world of robotics. Stay tuned for more and happy coding!"

[**Visual: End Screen with Series Title and Call-to-Action**]

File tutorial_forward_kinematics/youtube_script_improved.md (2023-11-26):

[**Intro Music**]

**Narrator:** "Welcome, tech enthusiasts and future roboticists! You're tuning in to our comprehensive tutorial series on building a spider robot. Whether you're just starting out or leveling up your skills, this guide is here to make your journey an enlightening one."

[**Visual: Series Title and Disclaimer Slide**]

**Narrator:** "Before we start, don't forget to check out our other tutorials in this series for a rounded understanding of the project. Each tutorial is crafted to build your skills, step by step. Find the complete series in the description below."

[**Visual Transition: Opening Slide for Today's Tutorial**]

**Narrator:** "Today, we're focusing on a crucial aspect of robotic movement in our spider robot - the forward kinematics method. Let's break down this concept and see how it brings our robot to life."

[**Visual: Diagram of Spider Robot**]

**Narrator:** "Imagine each leg of our robot as a mini-chain of joints and segments. Forward kinematics is our tool to figure out where the tip of each leg will be, based on the angles of these joints. Think of it like predicting where your hand ends up when you move your arm, without looking."

[**Visual: Basic Trigonometry Slide**]

**Narrator:** "To understand this better, we need to touch upon some trigonometry basics. Trigonometry is all about angles and sides of triangles. Don't worry, we'll keep it simple."

[**Visual: Sine, Cosine, and Tangent Illustrations**]

**Narrator:** "First, the sine of an angle in a right-angled triangle is a ratio - the length of the side opposite the angle to the triangle's longest side, called the hypotenuse. Cosine is similar, but it's the side next to the angle over the hypotenuse. Tangent is the sine divided by the cosine."

[**Visual: The Law of Cosines**]

**Narrator:** "Next, The Law of Cosines, a more generalized version of the Pythagorean theorem that applies to any triangle, not just right-angled ones.
The Law of Cosines helps us relate the lengths of the sides of a triangle to the cosine of one of its angles. It's particularly useful in robotics, where we often deal with non-right triangles formed by the robot's joints and limbs."

[**Visual: Transition to Spider Robot Leg Diagram**]

**Narrator:** "Now, let's apply these concepts to our spider robot's legs using the `forward_kinematics_naive` method."

[**Visual: Code Snippets and Leg Diagrams**]

**Narrator:** "We start by converting the angles of our robot's joints from degrees to radians. We use radians in these calculations because they provide a more natural way to describe angles in terms of their relation to the circle, which is essential in robotic movements."

[**Code Example: Angle Conversion**]

**Narrator:** "Next, we calculate the positions of each joint. Using sine and cosine, we find the x and y coordinates for our robot's hip joint, knee joint, and the foot."

[Visual: Highlighted Code Snippet]

Narrator: "First, we determine the x and y coordinates of the coxa-femur joint. This joint acts like the hip in a human leg, connecting the body to the upper leg segment."

[Visual: Illustration of Coxa-Femur Joint with Coordinates]

Narrator: "Using trigonometry, we calculate 'Xa', the horizontal position, and 'Ya', the vertical position, of this joint. We multiply the length of the coxa segment by the cosine and sine of the hip joint angle, respectively. This gives us precise coordinates based on our joint's current angle."

[Visual: Animated Calculation of Xa and Ya]

Narrator: "Next, we focus on the femur segment, the upper leg of our robot. We calculate its vertical and horizontal components. The vertical component, 'G2', is found by multiplying the femur's length by the sine of its angle, representing how high or low the knee will be."

[Visual: Illustration of Femur with Vertical Component]

Narrator: "Similarly, the horizontal component, 'P1', is the femur's length times the cosine of its angle. This tells us how far forward or backward the knee extends from the hip joint."

[Visual: Animated Calculation of G2 and P1]

Narrator: "Finally, we calculate the x and y coordinates of the femur-tibia joint. This joint, akin to a human knee, connects the upper and lower parts of the leg. By applying the horizontal component 'P1' to our previous calculations, we can pinpoint this joint's exact location in space."

[**Visual: Detailed Illustration of Spider Robot's Leg Joints**]

**Narrator:** "Let's focus on the foot joint, a key point in our leg's journey. We calculate the straight-line distance from the knee to the foot using the Law of Cosines."

[**Visual: Illustration of the Femur, Tibia, and Angles**]

**Narrator:** "The Law of Cosines helps us find one side of a triangle when we know the other two sides and the angle between them. Here, the sides are the femur and tibia, and the angle is at the knee."

[**Visual: Equation of the Law of Cosines**]

**Narrator:** "Here's the formula: The square of the length of the side we want to find is equal to the sum of the squares of the femur and tibia lengths, minus twice their product multiplied by the cosine of the knee angle. "

[**Visual: Calculation Steps for H**]

**Narrator:** "By plugging in the lengths of the femur and tibia, and the angle at the knee joint, we can solve for H, the straight-line distance from the knee to the foot."

[**Visual: Breaking Down H into Horizontal and Vertical Components**]

**Narrator:** "With H known, our next task is to break this distance into horizontal and vertical components - this will give us the 'Xb' and 'Yb' coordinates of the foot joint. To do this, we need to find additional angles at the knee and foot joint."

[**Visual: Trigonometric Formulas for Additional Angles**]

**Narrator:** "Using more trigonometry, we calculate these angles. We first find 'phi1', the angle at the knee joint, using the Law of Cosines again. This law helps us understand how H, the femur, and the tibia create an angle at the knee."

[**Visual: Equation for phi1**]

**Narrator:** "The formula for 'phi1' is \( \phi1 = \arccos\left(\frac{\text{FEMUR}^2 + H^2 - \text{TIBIA}^2}{2 \times \text{FEMUR} \times H}\right) \). This formula tells us how much the knee joint is bent."

[**Visual: Calculation of phi2 and phi3**]

**Narrator:** "Next, we calculate 'phi2', the angle at the foot joint. To calculate 'phi2', we determine the angle between the femur and the ground. This is done by subtracting the sum of 'phi1' and the angle of the tibia relative to the ground from 180 degrees. This provides us the angle at the foot joint. 'phi3', an auxiliary angle, is then determined by subtracting the original knee joint angle from 'phi1'. These angles are crucial for determining the position of the foot."

[**Visual: Horizontal and Vertical Projections of H**]

**Narrator:** "Now, we use 'phi3' to find the horizontal projection 'Pp' of the foot joint on the plane of the femur. This is calculated using the cosine of 'phi3' multiplied by H. The horizontal distance between the knee and the foot, 'P2', is then the difference between 'Pp' and the horizontal projection of the femur."

[**Visual: Final Calculation of Xb and Yb**]

**Narrator:** "Finally, we calculate 'Xb' and 'Yb', the x and y coordinates of the foot joint. These are found by using the sine and cosine of the original hip joint angle, multiplied by 'Pp'. The vertical component of the foot joint, 'G1', is found using the sine of 'phi3' and H, and it might be negated depending on the robot's coordinate system orientation."

[**Visual: Overview of Joint Position Mapping**]

**Narrator:** "Now, let's connect the dots between our calculations and the robot's joint positions. Each of these intricate calculations - from the Law of Cosines to the determination of angles 'phi1', 'phi2', and 'phi3' - plays a pivotal role in pinpointing the exact location of each joint in the robot's leg. The x and y coordinates we calculated for the hip, knee, and foot joints - 'Xa', 'Ya', 'Xb', 'Yb', and so on - are more than just numbers; they represent the precise spatial coordinates where each joint should be positioned. By mapping these coordinates onto our robot, we can visualize and control the movement and articulation of each leg with incredible accuracy. This precise mapping is what allows our spider robot to move fluidly and respond accurately to our commands, making the journey from mathematical concepts to mechanical reality."

[Visual: 3D Animation of Spider Robot’s Leg]

Narrator: "With our calculations complete, it's time to bring our spider robot's leg to life in the virtual world. Let's see how we map out its joints in our code."

[Visual: Highlighted Code Snippet]

Narrator: "Here, we're creating a list that represents the locations of each joint in the leg. This list is the bridge between our mathematical calculations and the robot's physical structure."

[Visual: Animation Showing Joint Locations Being Added to List]

Narrator: "We start with the origin point, [0, 0, 0], the base from where our leg begins. Next, we add the coordinates of the coxa-femur joint, calculated earlier as 'Xa' and 'Ya'. This joint is crucial as it connects the leg to the robot's body."

[Visual: Illustration of Coxa-Femur Joint with Coordinates]

Narrator: "Then, we move to the femur-tibia joint, the robot's knee equivalent. By adding 'Xc' and 'Yc' to our initial coxa-femur coordinates, and including the vertical component 'G2', we locate this joint precisely in three-dimensional space."

[Visual: Illustration of Femur-Tibia Joint with Coordinates]

Narrator: "Lastly, the tip of the leg, the point that interacts with the ground. Its coordinates are determined by adding 'Xb' and 'Yb' to the coxa-femur coordinates and using 'G1' as its vertical position. This marks the endpoint of our leg's journey."

**Narrator:** "And there you have it! By applying these trigonometric principles, we've precisely determined the position of our spider robot's foot joint."

[**Outro Music**]

**Narrator:** "I hope this tutorial lit up your path in the fascinating world of robotics. Stay tuned for more and happy coding!"

[**Visual: End Screen with Series Title and Call-to-Action**]

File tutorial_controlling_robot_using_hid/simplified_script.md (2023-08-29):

**Controlling a Robot with a Game Controller Using the GamepadController Class**

Ever used devices like keyboards or game controllers? If so, you've likely come across HID, or Human Interface Device. This system helps these devices talk easily with computers. The best part? Plug them in, and your computer instantly gets it.

Before we dive in, it's key to note: we'll be using a class I wrote named `GamepadController`. Also, make sure you have a Python setup ready to use.

And don't forget to connect your Radiomaster tx16s game controller. You can do this with a USB cable or wirelessly with Bluetooth.

Now, if you're back for more in our DIY spider robot series—welcome! If you're new, I'd suggest checking out our earlier episodes first.

Today, we'll cover:
1. Finding all connected HID devices.
2. Linking up with the game controller.
3. Understanding the signals from the controller.
4. Setting up the controller channels.
5. Moving the robot with the controller's commands.

For those wanting more details and tools, check out the description below.

Starting with **Step 1**: To see the connected HID devices, use the `list_hid_devices` method from the GamepadController class. We'll be mainly looking for the Radiomaster tx16s.

Moving to **Step 2**: Once you find the controller, it's time to connect. With the GamepadController class, this is simple. Just use the device's name, like "Radiomaster tx16s".

Next, **Step 3**: It's important to get how HID device data is sent. A single channel usually sends info using two different values: a main value and a multiplier. When mixed, they give a wider data range. The `GamepadController` class handles this with the `process_input` method. By using the `print_raw_data` method and moving the controller sticks, you'll see the signals change in real time.

Onto **Step 4**: Being exact is key. The GamepadController class lets you pick channels, like throttle and roll. After that, the `read_controller` method gives a quick view of each channel.

Wrapping up with **Step 5**: Now for the fun part! With the controller's signals, you can make the robot move and react.

In short, using a game controller to guide a robot mixes tech know-how with fun. A match made in heaven!

As we end today's session, a quick note: your likes and subscriptions push me to do more. Join in, learn, and let's explore tech together.

Until next time, keep learning and having fun!

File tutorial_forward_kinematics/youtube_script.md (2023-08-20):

[INTRO]

[ON SCREEN: Channel's Intro Animation]

Hello, everyone! Welcome back to our exciting series on building a spider robot. 

Before we start, just a quick reminder. This tutorial is part of a comprehensive series that I've created to guide you through the process of building a spider robot. Each tutorial in the series is designed to cover a specific aspect of the project, providing detailed instructions and insights to help you understand and replicate the steps. You can find the entire series linked in the description below. Whether you're a beginner or an expert, I hope you find these resources helpful and informative. Let's get building!

[MAIN BODY]

[ON SCREEN: Displaying the Jupyter Notebook]

Before we dive into the specifics, I want to point out that this repository includes a Jupyter Notebook that contains the code and visualizations. This can be a great resource as you follow along with this tutorial.

Today, we're focusing on a crucial aspect of robot motion planning - the Forward Kinematics Method. We're going to delve into this concept, specifically exploring the `forwardKinematicsNaive` method in our `SpiderLeg` class.

[ON SCREEN: Animation or diagram of a robot moving its limbs]

Now, if you're new to the term 'Forward Kinematics', it's a method we use in robotics to predict where the robot's limbs will be based on their joint angles. Essentially, it's about predicting the pose of a robot given its joint parameters.

For a spider-like robot, which could be a quadruped or hexapod robot, forward kinematics would involve determining the position of each of its feet given the angles of its joints. Each leg of the robot is typically a kinematic chain, with joints that allow movements in specific directions.

In practical terms, forward kinematics allows the robot to plan its movements. If the robot's brain decides to move a specific leg to a certain position, it can use inverse kinematics to calculate the necessary joint angles, then move the joints to those angles, and use forward kinematics to check that the leg ended up in the right place.

[ON SCREEN: Simple diagrams illustrating the trigonometric concepts]

Before we dive into the code, let's touch upon some basic trigonometry concepts that are used in this method. Don't worry if you're not a math person; I'll keep it simple.

We'll be talking about Sine, Cosine, Tangent, and the Pythagorean theorem. These concepts allow us to calculate the lengths of sides in a right triangle when an angle is known, or to find an angle when the lengths of the sides are known. They form the basis for many geometric calculations and transformations, including those used in our forward kinematics.

[ON SCREEN: Code on screen]

Now, let's dive deeper into our `forwardKinematicsNaive` method. This method calculates the position of each joint in the robot's leg based on the current angles of the joints.

Step 1. The code starts by checking if any joint angles were provided as input to the method. If no angles were provided, it uses the current angles of the leg.

Step 2. It then stores the current angles of the leg from the `SpiderLeg` object into the variable `angles`.

Step 3. The code then converts these angles from degrees to radians. This is because trigonometric functions in Python use radians, not degrees.

Step 4. The x and y coordinates of the joint between the coxa (or hip) and femur (or thigh) segments of the leg are calculated. This gives us the horizontal and vertical distances from the base of the leg to the hip joint.

Step 5. The code calculates the vertical component of the length of the femur segment. 

Step 6. We then compute the horizontal component of the length of the femur segment.

Steps 7. The x and y coordinates of the femur-tibia joint, or the "knee" of the spider leg, are calculated. These coordinates give us the position of the knee in relation to the base of the leg.

The next set of lines calculate the x, y, and z coordinates for the tibia-tip joint, which is the endpoint of the leg. The calculations involve trigonometric functions and geometric relationships to determine the position of this joint based on the angles of the other joints.

First, we calculate `H`, which represents the straight-line distance from the femur-tibia joint to the tibia-tip joint. This is done using the Law of Cosines, with the angle being the difference between 180 degrees and `theta3`. 

The `phi1`, `phi2`, and `phi3` values are auxiliary angles used to compute the position of the tibia-tip joint. 

Next, `Pp` represents the horizontal projection of the tibia-tip joint on the plane of the femur. 

`P2` is then calculated as the difference between `Pp` and `P1` (the horizontal projection of the femur-tibia joint). 

The final `x`, `y`, and `z` coordinates of the tibia-tip joint (`Xb`, `Yb`, and `G1`) are then computed using these auxiliary values.

The final output of the method is a list of joint locations, with each location represented by a list of x, y, and z coordinates.

That's it! You've just learned how the `forwardKinematicsNaive` method works. It's an elegant piece of code that uses simple trigonometry to calculate the position of each joint in the robot's leg based on the current angles of the joints.

Remember, the beauty of robotics lies not just in the final product, but in the intricate processes that bring the robot to life. 

[END]

I hope you found this tutorial helpful and that you now have a better understanding of the Forward Kinematics Method in robotics. If you did, please give this video a thumbs up, and don't forget to subscribe for more content like this. 

If you have any questions or suggestions, feel free to drop them in the comments below. I always love hearing from you all.

Until next time, happy coding and enjoy your robot-building journey!

[ON SCREEN: Outro Animation]

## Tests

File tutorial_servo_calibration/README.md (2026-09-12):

Read the companion tutorial on [Catch IT](https://catchit.pl/): [Calibrating Hexapod Servos with a Servo Tester](https://catchit.pl/blog/calibrating-hexapod-servos-with-a-servo-tester/).

> **Disclaimer:** This tutorial is part of a comprehensive series that I've created to guide you through the process of building a spider robot. Each tutorial in the series is designed to cover a specific aspect of the project, providing detailed instructions and insights to help you understand and replicate the steps.
> 
> You can find the entire series [here](../README.md). I encourage you to explore all the tutorials in the series to gain a complete understanding of the project. Whether you're a beginner or an expert, I hope you find these resources helpful and informative. Happy building!

# Servo Calibration with a Servo Tester

This tutorial guides you through the process of calibrating a servo using a servo tester. 

## Requirements

1. A servo motor
2. A servo tester
3. A power supply or batteries appropriate for your servo tester
4. A 3D model for precise calibration (optional)

## Resources

This repository includes a [Jupyter Notebook](servo_calibration.ipynb) that contains the code and visualizations. 

### 3D Model for Precise Calibration

To make the calibration process easier and more precise, I have prepared a 3D model specifically designed for popular servo sizes. This model includes template angles at -90, -45, 0, 45, and 90 degrees, as well as a gauge that you can place on the moving outer shaft of the servo.

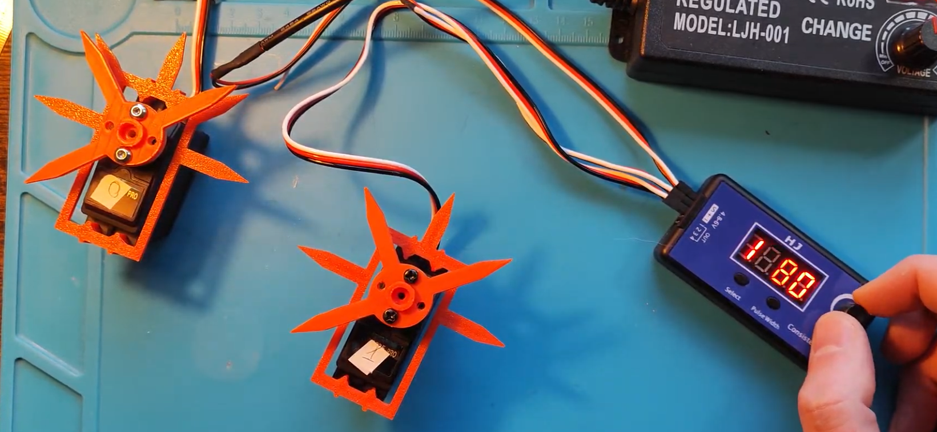
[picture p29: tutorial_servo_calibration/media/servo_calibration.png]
Servo calibration


By lining up the gauge with the template angles, you can get exact pulse width readings for those specific angles. This not only simplifies the process but also ensures that you achieve an accurate and consistent calibration across different servos. 
**You can download and 3D print this model [here](https://www.thingiverse.com/thing:6191213).**

## Steps

1. **Connect Servo to Servo Tester:** Plug the servo connector into the servo tester. The order usually is Signal-Positive-Negative (orange or white or yellow - red - black or brown).

2. **Power up the Servo Tester:** Connect your power supply or battery to the servo tester. Ensure you use the right voltage and current rating for your servo.

3. **Calibration and Testing:**
   - **Neutral Position:** Set the pulse width to 1500 μs (or any value suggested by the manufacturer) using the tester. This should move the servo to the 0 degree position.
   - **Negative and Positive 90 Degrees:** Slowly decrease the pulse width from 1500 μs until the servo moves to what you want to consider as -90 degrees. Note down the pulse width at this point. Then, increase the pulse width from 1500 μs until the servo reaches +90 degrees and note down the pulse width.
   - **Full Range:** By alternating the pulse width from minimum (for -90 degrees) to maximum (for +90 degrees), you can see the full range of motion of the servo. 
## Configuration File for the Spider Robot

The configuration file for the spider robot is a JSON file that includes essential data for the robot operation. It contains detailed information about the robot's dimensions, leg specifications, controller, and servo configurations.

```json
{
    "dimensions":[17.6,13.2,0],
    "legs":[
        {"size":[4.35,8.0,19.8],"position":[8.8, -6.6, 0],"rotation": [-45,0,180]},
        {"size":[4.35,8.0,19.8],"position":[8.8, 6.6, 0],"rotation": [45,0,180]},
        {"size":[4.35,8.0,19.8],"position":[-8.8, -6.6, 0],"rotation": [-135,0,180]},
        {"size":[4.35,8.0,19.8],"position":[-8.8, 6.6, 0],"rotation": [135,0,180]}
    ],
    "controller":{
        "port":"/dev/tty.usbmodem14201"
    },
    "servos": [
        {
            "pin": 0,
            "angle_range": [-90, 90],
            "reverse": true,
            "calibration_data": [1028, 1997, -45, 45],
            "offset":0
        },
        {
            "pin": 1,
            "angle_range": [-100, 110],
            "reverse": true,
            "calibration_data": [914,2210 , -90, 90],
            "offset":2
        },
        {"rest of servos e.g. pin 2-9 servos go ":"here"},
        {
            "pin": 10,
            "angle_range": [-100, 110],
            "reverse": false,
            "calibration_data": [867, 2155, -90, 90],
            "offset":6
        },
        {
            "pin": 11,
            "angle_range": [-70, 175],
            "reverse": false,
            "calibration_data": [814,2127 , -90, 90],
            "offset":72
        }
    ]
}

```

The `servos` key is an array that contains detailed configuration for each servo motor used in the robot. The servos are identified by their `pin` numbers. The `angle_range` key holds the minimum and maximum angles the servo can rotate. The `reverse` key specifies if the direction of the servo needs to be reversed.

The `calibration_data` is the critical aspect for our tutorial. It's an array of four values: the minimum and maximum PWM signals, followed by the angles those pulses correspond to. Together they define the linear mapping between PWM signals and angles, which we'll use later to control the servos accurately. 

The `offset` key holds the value of the deviation from the zero position, which can be added or subtracted to adjust the servo's zero position due to mechanical misalignments.

By properly setting up this configuration file, we can precisely control the robot's movements, ensuring that each part works in unison to achieve the desired behavior.

## Important note: Relationship between pulse width and servo angle

For visualizing the relationship between pulse width and servo angle, a Python script can be found [in this Jupyter notebook](servo_calibration.ipynb).

The notebook will plot the measured pulse widths (x-axis) and corresponding angles (y-axis). The plot will have two lines:

- The blue line represents the actual measured positions.
- The gray dashed line represents an approximation.

A "linear approximation" is a simplified representation of data that assumes the relationship between two variables can be represented by a straight line. The concept comes from the field of mathematics, where it's often useful to approximate complex functions with simpler ones.

In the context of a servo motor, we often assume the relationship between pulse width (input) and the angle of the servo arm (output) is linear. This means we expect the servo arm to move at a constant rate as we increase the pulse width. For example, if increasing the pulse width by 100 µs causes the servo arm to move by 10 degrees, we expect that increasing the pulse width by 200 µs will move the servo arm by 20 degrees, and so on.

However, this relationship isn't always perfectly linear in real servos. Mechanical imperfections, non-linear electronics, or other factors may cause the servo to deviate from the expected linear behavior. That's why it's helpful to measure the actual response of the servo and compare it to the linear "perfect" approximation.

Here's what's being plotted in the previous code:
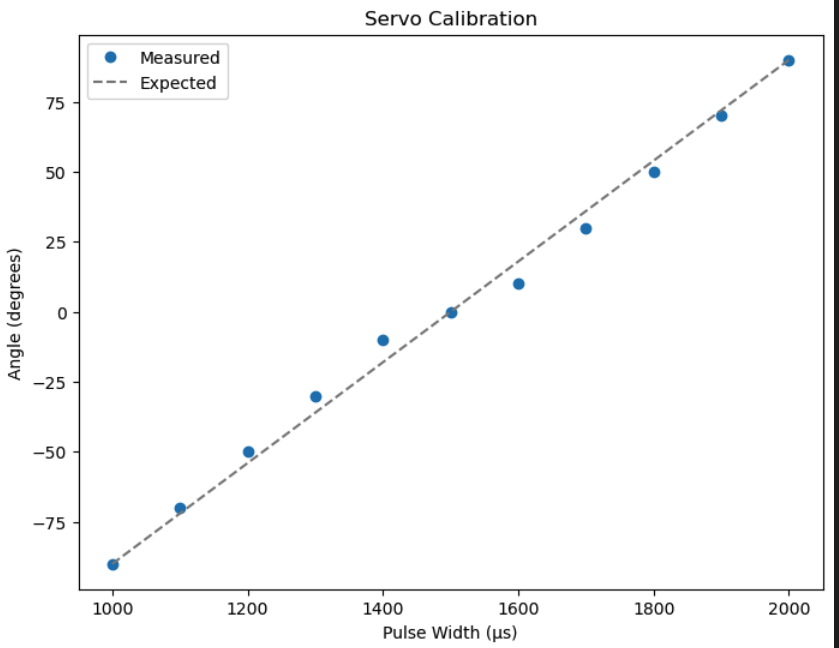
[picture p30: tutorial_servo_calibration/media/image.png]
Relationship between pulse width and servo angle


The pulse_widths and angles lists represent the actual measured response of the servo. The plt.plot(pulse_widths, angles, marker='o') line plots these values as blue dots on the graph.

The pulse_width_range and angle_range lists represent the expected linear response of the servo, based on the assumption that the servo moves 90 degrees when the pulse width changes by 500 µs. The plt.plot(pulse_width_range, angle_range, '--', color='gray') line plots this expected response as a dashed gray line on the graph.

By comparing the actual response to the expected linear response, you can see how much your servo deviates from the expected behavior. If the blue dots fall on the gray line, your servo behaves exactly as expected. If the blue dots deviate from the gray line, it means your servo doesn't move at a constant rate, and you might need to take this into account in your project.

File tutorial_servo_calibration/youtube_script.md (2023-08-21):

[INTRO]

[ON SCREEN: Preview of the spider robot in action]

Ever seen a spider robot in action?
Well, in this series, we're rolling up our sleeves and crafting our very own!
Using materials that are easy to find, we're crafting a DIY spider robot, and I'm inviting you to join me on this adventure.
Now, a small confession: I'm learning as I go. Some challenges still puzzle me, and the beauty of this series is that we'll tackle them together, step by step. I believe It's the essence of DIY—learning, iterating, and improving.
If you're just tuning in, I suggest starting from the beginning to get the full experience. [ON SCREEN: Link to the playlist]
Throughout this series, I'll break down each part of the project, ensuring you can follow along with ease and maybe even kickstart your own robotic creation.
I aim to keep these sessions short and to the point. However, if anything feels a bit rushed or unclear, don't hesitate to pause or rewind. Additionally, I've provided supplementary documentation and Jupyter notebooks to help reinforce and expand on what I cover. Remember, it's about the journey and understanding, not the pace.
For those curious about the tools, you'll find all the details in the description below. Join me, and let's embark on this exciting DIY voyage together!

[REQUIREMENTS]

Hey everyone! Today, let's talk about why calibrating servos is a must-do:

Consistency: Servos, even of the same model, can behave differently due to manufacturing variations. Calibration ensures they all work uniformly.

Accuracy: For projects needing exact movements, like our spider robot, even a wee error can be a big issue. Calibration ensures each move is spot-on.

Safety and Reliability: Uncalibrated servos can cause unexpected motions, which might damage your project or even pose risks. Calibrating them makes sure they act predictably.

Max Performance: Calibration helps you get the most out of your servo, from its full range of motion to efficient power use.

In short, if you want your servos to work reliably, safely, and at their best, calibration is the key. Stay tuned for our step-by-step guide on how to do it right!

We're taking an important step in this process: adjusting the servos using a servo tester.

[ON SCREEN: List of Requirements]

You need a few things: A servo motor, a servo tester, and a power supply or batteries that work with your servo tester.

[STEPS]

[ON SCREEN: Close-up of the servo, servo tester, and power supply]

Ok, let's start the adjusting process.
The first step is to connect the servo to the servo tester.
The servo has a cable with three wires.
Usually, these wires are red, black, and white or yellow.

The red wire is for power (also known as the VCC).
The black wire is for ground.
The white or yellow wire is for the signal (often marked with an 'S' on the servo tester).
Connect these wires to the matching ports on the servo tester.
The servo tester usually has three sets of pins: 'S' for signal, '+' for power, and '-' for ground.

[ON SCREEN: Close-up of the power supply connection]

After the servo is connected, it's time to turn on the tester.
On your servo tester, you'll usually find separate ports for the power supply, often marked as 'VCC' and 'GND' or '+', '-'.

For the model I'm using, the HJ Digital Servo Tester, the first pins are for connecting the battery or power supply.
Connect the positive wire of your power supply to the '+' pin and the negative wire to the '-' pin.

With everything connected and turned on, we're ready to start the adjusting and testing.
Let's calibrate our servo. 
Set it to the middle, or 0 degrees. 
Then, move it to -90 degrees and note the pulse width. 
Do the same for +90 degrees. Keep in mind, these angles, -90 and +90, are just examples; 
you can choose others based on your needs. 
Remember these pulse widths; they help control the servo accurately in future projects.
The last step is to check the full movement of the servo.

[3D MODEL]

[ON SCREEN: 3D Model]

To make this process easier and more accurate, I've made a 3D model designed for popular servo sizes.
This model includes template angles and a gauge that you can put on the moving outer part of the servo.
You can download and 3D print this model; I've put the link in the description below.

[CONFIGURATION FILE]

[ON SCREEN: Displaying the JSON configuration file]

In our spider robot project, we use a JSON configuration file to store all the important details about the robot's sizes, leg details, controller, and servo settings.
Today, I'm focusing on the servos key.

[ON SCREEN: Zoom in on servos key]

The servos key is a list containing detailed settings for each servo motor used in the robot.
Each servo is identified by its pin number, which matches the physical pin on the controller that it's connected to.

[ON SCREEN: Highlight pin, angle_range, reverse, calibration_data, offset in the JSON]

Let's explain the keys in the servo setting:

angle_range: This is a list that holds the smallest and biggest angles the servo can rotate.
reverse: This true or false value tells if the direction of the servo needs to be reversed.
calibration_data: The calibration_data key usually contains a list of two pairs of matching values.
The first pair is the pulse width values (in microseconds) for the arbitrary, chosen by you positions of the servo.
The second pair is the matching angles (in degrees) that these pulse width values represent.
For example, a servo might have a calibration_data list like this: 

[1000, 2000, -90, 90].
This means that a pulse width of 1000 microseconds matches an angle of -90 degrees, and a pulse width of 2000 microseconds matches an angle of +90 degrees.
offset: This is the difference from the zero position, which can be adjusted to fix for mechanical misalignments.

[ON SCREEN: Highlight the calibration_data in the JSON]

Among these, calibration_data is the most important for our current video.
These values are very important for mapping PWM signals to specific angles, which we'll use later to control the servos accurately.
With these settings, we can control the robot's movements accurately, making sure that each part works together to achieve the wanted behavior.

[RELATIONSHIP]

[ON SCREEN: Displaying the plot of pulse width vs servo angle]

Now, let's understand the relationship between pulse width and servo angle.
I'll use Python to show this relationship.
In a perfect world, this relationship would be a straight line - a constant increase in pulse width would result in a constant rotation of the servo arm.
But in reality, because of mechanical imperfections and other factors, real servos can be different from this perfect behavior.
By plotting the actual response of the servo, we can see how much the servo is different from the expected behavior.

[CONCLUSION]

[ON SCREEN: Channel's Outro Animation or Logo]

That's all for this video on servo adjusting!
I hope you've found it helpful.
Remember, understanding your servo's behavior is key to making your spider robot move smoothly and accurately.
[END]

I hope you found this video helpful! If you did, please give it a thumbs up and consider subscribing if you want to see more like this. Don't hesitate to drop any questions or suggestions in the comments below. I love hearing from you all.

We have many more exciting topics to cover in the upcoming videos, so stay tuned! Until then, keep exploring, and happy robot building!

[ON SCREEN: Outro Animation]

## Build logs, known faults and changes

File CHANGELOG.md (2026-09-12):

# Changelog

All notable changes to the Spider Robot Tutorials are documented in this file.

The format is based on [Keep a Changelog](https://keepachangelog.com/en/1.1.0/),
and entries are grouped by date (the repository does not use version tags).

## 2026-09-12

### Added

- `CHANGELOG.md` (this file) and `AGENTS.md` instructions for AI coding agents, requiring every change to include a changelog entry.
- `requirements.txt` listing the notebook and script dependencies (jupyter, ipympl, numpy, matplotlib, opencv-python, hidapi, pyserial).
- Missing `tutorial_controll_one_leg/README.md` with the series boilerplate and an overview of the folder's files.

### Changed

- Inverse kinematics (`spider_leg.py`, the IK notebook, and the IK tutorial) now use `atan2(y, x)` and compute the horizontal projection `P` with the Pythagorean theorem, so IK works for targets with x ≤ 0 and for legs pointing straight along the Y axis. Verified with forward/inverse round-trip tests; previously such targets returned mirrored angles or crashed.
- Forward kinematics README refers to the actual method name `forward_kinematics_naive` and marks its code block as Python.
- Servo calibration README: corrected the pulse-width-to-angle relationship to 90° per 500 µs to match the notebook, and reworded the `calibration_data` description to match the `Servo.angle()` implementation.
- HID tutorial pseudocode now guards against `read_controller()` returning `None`.
- Root README table of contents: linked the HID tutorial and the one-leg tutorial (previously "TBD").
- `spider_leg.py` and the IK notebook dropped an unused `numpy` import, making the module pure standard library.
- Tools & hardware README copy edits: "XT16S" corrected to "TX16S" and minor grammar.

### Fixed

- Empty TOC link for "Controlling Your Robot Using USB or Bluetooth HID Devices" in the root README.
- Empty Aliexpress link for the soldering iron, odd `image/../media/...` image paths, and a lazy `![Alt text]` in the tools & hardware README.
- Typos: "Artificial Inteligence", "projectiona", "Calculation Proces", "tar4get", "Aliepxress", "touch_treshold", a stray quote, and copy-pasted "Top view" alt texts on side-view images.
- `hardware_controller.py`: copy-pasted `NotImplementedError` messages named the wrong methods, and `receivedValues` was initialized after the reader thread started (race condition).
- `controller.py`: removed unused `vendor_id`/`product_id` parameters from `print_raw_data`.
- `one_leg_controll.ipynb`: removed the broken `project_path_on_rectangle` stub, which returned an undefined variable and was superseded by `project_path_on_plane`.

### Removed

- Obsolete draft `tutorial_tools_hardware_3d_parts_spider_robot/_README.md`, superseded by that folder's README.

## 2026-09-07

### Added

- Catch IT companion-article links to the root README and to each tutorial README.

## 2025-11-24

### Added

- Critical power backfeed safety warning to the tools & hardware tutorial (battery + USB simultaneously), reviewed for technical accuracy in PR #2.

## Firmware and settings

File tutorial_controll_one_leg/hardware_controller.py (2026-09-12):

import json
import serial
import time
import os
from collections import deque
import threading

class Servo:
    def __init__(self, pin, angle_range, reverse=False, offset=0):
        self.pin = pin
        
        self.pulseRange = [1000, 2000]
        self.reverse = reverse
        self.angleRange = angle_range
        #if self.reverse:
        #    self.angleRange=[i * (-1) for i in angle_range]
        self.offset = offset
        self.calibration_data = None
        self._pulseWidth = 1500
    # http://learnwebgl.brown37.net/08_projections/projections_mapping.html
    # Given a value p in the range A to B, calculate a point q in the range C to D that is in the same relative place.
    def _map(self,p,A,B,C,D):
        scale = (D-C)/(B-A)
        offset = -A*(D-C)/(B-A) + C
        q = p*scale + offset
        return q

    def pulseWidth(self, value=None):
        if value is None:
            return self._pulseWidth
        else:
            #angle = self._map(value,self.calibration_data[0],self.calibration_data[1],self.calibration_data[2],self.calibration_data[3])
            #angle += self.offset
            #if (self._validate_angle(angle)):
            self._pulseWidth=value
    def _validate_angle(self,angle):
        if not (min(self.angleRange) <= angle <= max(self.angleRange)):
                raise ValueError(f"Servo with pin {self.pin} - angle {angle} OUT OF RANGE {self.angleRange}")
        return True
    def calibration(self, pulse_1, pulse_2,angle_1, angle_2):
        self.calibration_data = (pulse_1, pulse_2,angle_1, angle_2)
    def angle(self, angle=None):
        if angle is None:
            pulse_width = self.pulseWidth()
            angle = self._map(pulse_width, self.calibration_data[0], self.calibration_data[1], self.calibration_data[2], self.calibration_data[3])
            if self.reverse:
                angle = -angle
            angle += self.offset
        else:
            self._validate_angle(angle)
            angle -= self.offset
            if self.reverse:
                angle = -angle
            pulse_width = self._map(angle, self.calibration_data[2], self.calibration_data[3], self.calibration_data[0], self.calibration_data[1])
            self.pulseWidth(pulse_width)
        return angle

    def __str__(self):
        return f"Servo(pin={self.pin}, angle_range={self.angleRange}, reverse={self.reverse}, offset={self.offset}, calibration_data={self.calibration_data}, pulse_width={self._pulseWidth})"



class HardwareController:
    def __init__(self, config_file):
        self.servos = {}

        with open(config_file, 'r') as f:
            config = json.load(f)
        self.port= config['controller']['port']
        for servo_config in config['servos']:
            pin = servo_config['pin']
            angle_range = servo_config['angle_range']
            reverse = servo_config['reverse']
            calibration_data = servo_config['calibration_data']
            offset = servo_config.get('offset', 0)  # Get the offset value, default to 0 if not present

            servo = Servo(pin, angle_range, reverse, offset)
            servo.calibration(*calibration_data)
            self.servos[pin] = servo
    def servos_enabled(self, enable: bool):
        pass

    def sync(self):
        start_index = None
        values = []

        for pin, servo in sorted(self.servos.items()):
            if start_index is None:
                start_index = pin
            values.append(servo.pulseWidth())

        self.send_set_command(start_index, values)

    def move_servo_to_angle(self, pin, angle):
        if pin in self.servos:
            self.servos[pin].angle(angle)
        else:
            raise ValueError(f"Servo with pin {pin} not found")
    def send_get_sensors(self, start_index, values):
        raise NotImplementedError("send_get_sensors() method must be implemented in the derived class")
    
    def send_set_command(self, start_index, values):
        raise NotImplementedError("send_set_command() method must be implemented in the derived class")

    def send_get_command(self, start_index, count):
        raise NotImplementedError("send_get_command() method must be implemented in the derived class")

    def read_from_server(self):
        raise NotImplementedError("read_from_server() method must be implemented in the derived class")

    def get_received_data(self, timeout=0.01):
        raise NotImplementedError("get_received_data() method must be implemented in the derived class")
        
    def legs_in_contact(self):
        raise NotImplementedError("legs_in_contact() method must be implemented in the derived class")
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

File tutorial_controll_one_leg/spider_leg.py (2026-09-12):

from math import degrees, radians, cos, sin, sqrt, asin, acos, atan2

class SpiderLeg:
    def __init__(self, name, COXA, FEMUR, TIBIA):
        self.name = name
        self.COXA = COXA
        self.FEMUR = FEMUR
        self.TIBIA = TIBIA
        self.theta1 = 0.
        self.theta2 = 0.
        self.theta3 = 0.

        # Forward kinematics calculates the target position (x, y, z) based on the joint angles
        self.joints = self.forwardKinematics()

    def setAngles(self, angles):
        """
        Set the joint angles for the leg.
        
        Args:
            angles (list): A list of three angles in degrees, corresponding to theta1, theta2, and theta3.
            
        Returns:
            list: The updated joint angles.
        """
        angles = self.normalizeAngles(angles)
        self.theta1, self.theta2, self.theta3 = angles
        return self.getAngles()

    def getAngles(self):
        """
        Get the current joint angles.
        
        Returns:
            list: A list containing the current joint angles (theta1, theta2, theta3) in degrees.
        """
        return [self.theta1, self.theta2, self.theta3]

    def normalizeAngles(self, angles):
        """
        Normalize joint angles to be in the range [-180, 180] degrees.
        
        Args:
            angles (list): A list of joint angles in degrees.
            
        Returns:
            list: A list of normalized joint angles in degrees.
        """
        for idx, ang in enumerate(angles):
            sign = 1
            if ang < 0:
                sign = -1
            angles[idx] = sign * (abs(ang) % 360)
            if abs(ang) > 180:
                angles[idx] = ang - (360 * sign)
        return angles

    def getTarget(self):
        """
        Get the target position of the leg tip.
        
        Returns:
            list: A list containing the x, y, and z coordinates of the leg tip.
        """
        return self.joints[3]

        # Calculate the joint angles required to reach a target position using inverse kinematics
    def inverseKinematics(self, target=None):
        if target is None:
            target = self.joints[3]
        x, y, z = target[0], target[1], target[2]

        # Calculate theta1 using arctangent (tan^-1) based on x and y coordinates
        # atan2(y, x) gives the angle of a right-angled triangle with legs x and y;
        # unlike plain atan(y/x), it also keeps track of the quadrant and works when x is zero
        theta1 = atan2(y, x)

        # Calculate intermediate values for theta2 and theta3
        # Here, we apply trigonometric rules to find the lengths of the sides of the triangles
        # We use the cosine and sine functions to find the lengths Xa and Ya
        Xa = self.COXA * cos((theta1))
        Ya = self.COXA * sin((theta1))

        Xb = x - Xa
        Yb = y - Ya

        # P is the hypotenuse of the right-angled triangle with legs Xb and Yb:
        # the horizontal distance from the end of the coxa to the target point.
        # Computed with the Pythagorean theorem so it stays accurate also when
        # the leg points straight along the Y axis (cos(theta1) == 0)
        P = sqrt(Xb ** 2 + Yb ** 2)

        # Calculate the absolute value of z, which will be used in the calculation of H
        G = abs(z)

        # Use Pythagorean theorem to find the length H (the hypotenuse of a right-angled triangle with legs P and G)
        H = sqrt(P ** 2 + G ** 2)

        # Calculate the angle phi3 using arcsine (sin^-1) based on G and H
        # arcsin(G/H) gives the angle of a right-angled triangle with legs G and H
        phi3 = asin(G / H)

        # Apply the cosine rule to find the angle phi2
        # Cosine rule: (c^2 = a^2 + b^2 - 2ab * cos(C))
        # We rearrange the formula to find the cosine of angle C:
        # cos(C) = (a^2 + b^2 - c^2) / (2ab)
        # In our case, a = self.TIBIA, b = H, c = self.FEMUR
        phi2Acos = ((self.TIBIA ** 2) + (H ** 2) - (self.FEMUR ** 2)) / (2 * self.TIBIA * H)
        phi2 = acos(phi2Acos)

        # Apply the cosine rule again to find the angle phi1
        # In this case, a = self.FEMUR, b = H, c = self.TIBIA
        phi1 = acos((self.FEMUR ** 2 + H ** 2 - self.TIBIA ** 2) / (2 * self.FEMUR * H))

        # Calculate theta2 and theta3 based on phi values and the sign of z
        # If z is positive, theta2 = phi1 + phi3; otherwise, theta2 = phi1 - phi3
        if z > 0:
            theta2 = phi1 + phi3
        else:
            theta2 = phi1 - phi3

        # Calculate theta3 as the sum of phi1 and phi2
        theta3 = phi1 + phi2

        # Update joint angles and forward kinematics with the new angles
        ang = [degrees(theta1), degrees(theta2), degrees(theta3)]
        self.setAngles(ang)
        self.forwardKinematics()
        return ang


    # Calculate the joint positions (x, y, z) based on the given joint angles using forward kinematics
    def forwardKinematics(self, angles=None):
        if angles is None:
            angles = [radians(self.theta1), radians(self.theta2), radians(self.theta3)]
        theta1, theta2, theta3 = angles

        # Calculate the positions of each joint based on the given angles
        Xa = self.COXA * cos((theta1))
        Ya = self.COXA * sin((theta1))
        G2 = sin(theta2) * self.FEMUR
        P1 = cos(theta2) * self.FEMUR
        Xc = cos(theta1) * P1
        Yc = sin(theta1) * P1

        # Calculate the position of the tip of the leg (end effector)
        H = sqrt(self.TIBIA ** 2 + self.FEMUR ** 2 - (2 * self.TIBIA * self.FEMUR * cos(radians(180) - theta3)))
        phi1 = acos((self.FEMUR ** 2 + H ** 2 - self.TIBIA ** 2) / (2 * self.FEMUR * H))
        phi2 = radians(180) - (radians(180) - theta3) - phi1
        phi3 = (phi1 - theta2)
        Pp = cos(phi3) * H
        P2 = Pp - P1
        Yb = sin(theta1) * Pp
        Xb = cos(theta1) * Pp
        G1 = sin(phi3) * H
        G1 = -G1

        # Store the joint positions in a list
        jointLocation = [
            [0, 0, 0],  # start joint
            [Xa, Ya, 0],  # coxa-femur joint
            [Xa + Xc, Ya + Yc, G2],  # femur-tibia joint
            [Xa + Xb, Ya + Yb, G1]  # tip of the leg
        ]

        self.joints = jointLocation
        return jointLocation

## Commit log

2023-05-06 added fusion file and usage section to the notebook
    [Hexapod_Leg_Fusion360.f3d]
2023-07-15 remove numbering from tutorial folder.
    [Hexapod_Leg_Fusion360.f3d]
2023-11-14 updated forward kinematics script
2024-01-07 images for forwrd kinematics
2024-02-09 inverse kinematics script update
2024-02-18 one leg started
2025-11-24 Add critical power safety warning to hardware tutorial
2025-11-24 Fix technical accuracy in power safety warning
2026-09-12 Fix tutorial quality issues: links, typos, doc/code mismatches, IK edge cases
    - Root README: link HID tutorial in TOC, link one-leg tutorial (was TBD),
    fix 'Artificial Inteligence' typo
    - Add missing tutorial_controll_one_leg/README.md (series boilerplate + file list)
    - spider_leg.py and IK notebook: use atan2 and Pythagorean P so IK works for
    x<=0 targets (verified by FK round-trip tests); drop unused numpy import
    - IK README: fix 'projectiona'/'Proces' typos, stray quote, side-view image
    alt texts, soften unimplemented validation claim, document atan2/P change
    - FK README: use actual method name forward_kinematics_naive, add python
    code-fence tag
    - Servo calibration README: correct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
    [hardware_controller.py, spider_leg.py]
2026-09-12 Add CHANGELOG.md and AGENTS.md changelog policy
    - CHANGELOG.md: documents the 2026-09-12 quality pass and notable earlier
    changes (Catch IT links, power backfeed warning), Keep a Changelog format
    - AGENTS.md: instructions for AI agents, requiring every change to include
    a changelog entry in the same commit
    - README: link the changelog from the Contributing section
